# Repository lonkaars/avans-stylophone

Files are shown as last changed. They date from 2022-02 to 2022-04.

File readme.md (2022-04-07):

# avans-stylofoon

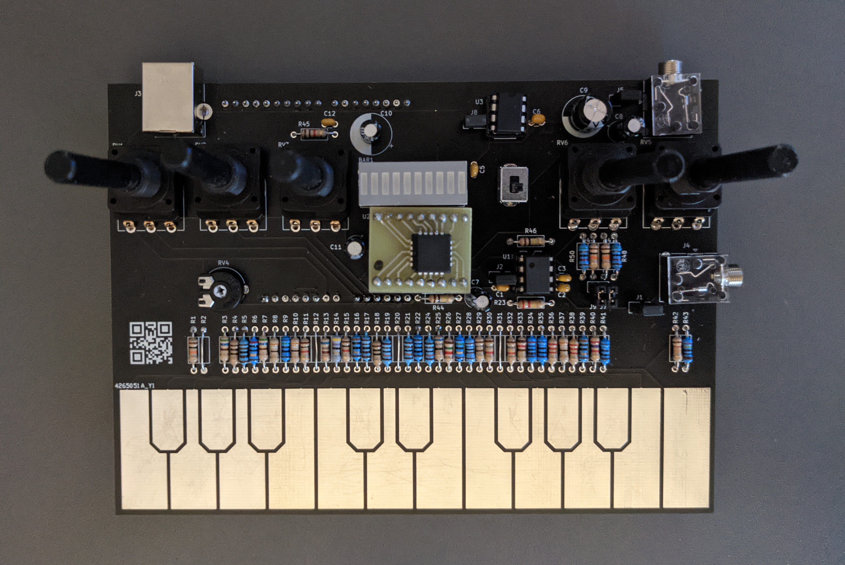
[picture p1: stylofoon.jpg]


(dutch)

bronnen voor project stylofoon van technische informatica bij hogeschool avans
in den bosch. hier staan alle kicad bestanden voor de elektrische schema's en
hardwareontwerpen, en alle documentatie die ingeleverd moet worden.

## advies voor andere studenten die dit project ook moeten doen

- Lees goed wat de 'gain' van de LM386 doet
- Maak je system requirements een beetje vaag (zie mijn system requirements),
	zo verlies je geen punten wanneer het uiteidendelijk blijkt dat je stylofoon
	ontzettend vals klinkt omdat de weerstanden niet helemaal kloppen
- Uitbereidingen zijn leuk, maar als ik het project opnieuw zou doen zou ik
	gewoon voor de 8 drukknoppen en shiftregister gaan, want uitbereidingen maken
	bij de stylofoon is lastig
- Onderzoek goed hoe je een constante 'drone'-toon kan vermijden (als je gaat
	voor de vco opstelling van de 555, de rco is hier waarschijnlijk niet
	gevoelig voor), anders maakt je stylofoon een contstante middentoon, inplaats
	van dat het stil is als je geen toets aanspeelt
- Er staan Sony speakers in het techlab, deze werken (in mijn geval slecht) en
	zorgde er (onder andere) voor dat mijn VU-display het niet goed deed.
- Speaker specificaties verschillen niet alleen in impedantie, maar ook enorm
	in gevoeligheid, dus het kan makkelijk aan de speaker liggen als je stylofoon
	geen 'fatsoenlijk volume' produceert.
- Maak veel system tests voor dingen die toch wel zullen werken, uiteidenlijk
	word je eindcijfer voor werking bepaald door het percentage van behaalde
	system tests, en onder de 90% geeft je al een 4. Dus als je bijvoorbeeld 18
	tests hebt kun je er maar 1 missen om nog een voldoende te halen.

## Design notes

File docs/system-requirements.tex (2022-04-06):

\documentclass[12pt, a4paper, dutch]{article}
\usepackage[margin=1in]{geometry}

\usepackage{float}
\usepackage{babel}
\usepackage{siunitx}
\usepackage{amsmath}
\usepackage{csquotes}
\usepackage{parskip}
\usepackage{unicode-math}
\usepackage{fontspec}
\usepackage{tabularx}
\usepackage{booktabs}
\usepackage{needspace}
\usepackage{graphicx}
\usepackage{hyperref}
% \usepackage[backend=biber,
% 	bibencoding=utf8,
% 	style=apa
% ]{biblatex}

\setmainfont{TeX Gyre Schola}
\setmathfont{TeX Gyre Schola Math}
\sisetup{
	group-separator = {.},
	output-decimal-marker = {,}
}

\bigskipamount=7mm
\medskipamount=4mm
\parindent=0mm

\newcommand{\req}[1]{$^{\text{\ref{req:#1}}}$}
\newcommand{\up}[1]{$^{\text{#1}}$}
\newcommand{\sub}[1]{$_{\text{#1}}$}

\begin{document}
System requirements \hfill \textbf{Loek Le Blansch (2180996)}\\
Project Stylofoon \hfill \today
\medskip

\section{Inleiding}

De stylofoon is een klein instrument die met behulp van een stylus bespeeld wordt. Op
de stylofoon zitten 20 contactpunten in de vorm van pianotoetsen. Het uiteinde van de
stylus bevat een elektrisch contact, die gebruikt wordt om de pianotoetsvormige
contacten aan te raken. De stylofoon heeft twee ingebouwde synthesizers, die mengbaar
zijn met behulp van een draaiknop om unieke geluiden te cre\"eren.

\begin{figure}[H]
	\centering
	
	\caption{Schets van de layout op de voor- en bovenkant}
\end{figure}

\section{Projectopdracht}

Hier is het originele verhaal van de opdrachtgever, met toegevoegde nummers om aan te
tonen hoe bepaalde eisen verwerkt zijn:

``Ik wil graag één muziekinstrument\req{20keys} die op twee verschillende manieren
geluid kan produceren\req{engines}, met een Stylofoon en Synthesizer. De Stylofoon
moet 20 tonen kunnen genereren\req{20keys}. De Synthesizer moet gebaseerd zijn op een
Arduino\req{engines} en 8 variabele tonen maken\req{readtone}\up{,}\req{wavform}. De
tonen die de Synthesizer maakt moeten met draaiknoppen instelbaar zijn op frequentie
en lengte\req{env}. Er moet een schakelaar aanwezig zijn om te wisselen tussen
het afspelen van de Stylofoon en Synthesizer\req{mixfader}. Het geluidsignaal moet
ook visueel gemaakt worden op een VU-meter\req{vumeter}. Het volume moet ingesteld
kunnen worden met een draaiknop\req{volknob}. De status van het gehele instrument
moet visueel weergegeven worden\req{powerbutton}. Het zou mooi zijn als in plaats van
een schakelaar er een manier is om de geluidssignalen van de Stylofoon en Synthesizer
te combineren\req{mixfader}.

De Stylofoon heeft minimaal 20 contactpunten\req{20keys} en is gebaseerd op een 555
timer\req{555}. De Synthesizer is gebaseerd op een Arduino Uno\req{engines} en heeft
minimaal 8 druktoetsen\req{readtone} en 2 draaiknoppen\req{digsoundtweak}. Verder is
er een draaiknop om het volume te regelen\req{volknob}, een
luidspreker-aansluiting\req{phonesout} en een VU-meter\req{vumeter}. Alleen pinnen
A0-A5 van de Arduino Uno mogen gebruikt worden\req{a05}.''

\section{Technische eisen}

In deze vereisten word er met het woord `synthesizer' alleen het elektrische
onderdeel dat een geluidssignaal produceert bedoeld, niet de stylofoon in zijn
geheel.

\begin{enumerate}
\subsection{Functionele specificaties}
	\item \label{req:20keys} \'E\'en fysiek klaviertoetsenbord bestaand uit 20
		elektrisch geleidende contacten
	\item \label{req:mixfader} Een draaiknop die het geluid van de analoge en de
		digitale synthesizers mixt voordat het signaal versterkt wordt
	\item \label{req:vumeter} Een 10-segments VU-meter die visueel de amplitude van het
		uigangssignaal laat zien
	\item \label{req:volknob} Een volumeknop om het uigangsvolume aan te passen
	\item \label{req:powerbutton} Een aan-uit knop op de voorkant die toont of de stylofoon
		aan staat
	\item \label{req:digsoundtweak} Draaiknoppen om eigenschappen van het geluid dat
		uit de digitale synthesizer komt aan te passen:
	\begin{enumerate}
		\item \label{req:toonsnelheid} \'E\'en draaiknop om de toonsnelheid te regelen
		\item \label{req:env} \'E\'en draaiknop om de `envelope' te regelen
		\item \label{req:wavform} \'E\'en draaiknop om de golfvorm te mengen of schakelen
			tussen een sinus-, driehoeks-, zaagtand- en blokgolf.
	\end{enumerate}
\subsection{Operationele functies}
	\item \label{req:engines} Twee synthesizers, een analoge en een digitale die met
		behulp van een Arduino Uno gemaakt wordt
	\begin{enumerate}
		\item \label{req:wavforms} De digitale synthesizer produceert vier verschillende
			golfvormen
		\item \label{req:readtone} De digitale synthesizer kan de huidige toon die
			gespeeld word uitlezen door de spanning over de weerstandsladder te meten
	\end{enumerate}
	\item \label{req:phonesout} De audio uitgang van de stylofoon wordt intern
		versterkt zijn om op headphone-level te komen
\subsection{Ontwerpbeperkingen}
	\item \label{req:555} De analoge synthesizer is gebaseerd op een 555 timer
	\item \label{req:a05} Alleen pinnen A0..A5 van de Arduino worden gebruikt
	\item \label{req:lm3914} Er wordt een LM3914 IC gebruikt voor de VU-meter
\subsection{Randvoorwaarden}
	\item Sommige componenten worden voorgeschreven
	\item Diverse componenten zoals de gaatjesprint, druktoetsen en leds worden door de
		labbeheerders geleverd
	\item Componenten die niet in voorraad zijn worden in overleg met de labbeheerders
		gekozen
	\item Er worden IC-voetjes gebruikt om de ledbar van de VU-meter, en andere IC's te
		monteren
\end{enumerate}

\end{document}

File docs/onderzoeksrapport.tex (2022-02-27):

\documentclass[12pt, a4paper, dutch]{article}
\usepackage[margin=1in]{geometry}

\usepackage{float}
\usepackage{babel}
\usepackage{siunitx}
\usepackage{amsmath}
\usepackage{csquotes}
\usepackage{parskip}
\usepackage{unicode-math}
\usepackage{fontspec}
\usepackage{tabularx}
\usepackage{booktabs}
\usepackage{needspace}
\usepackage{hyperref}
\usepackage{graphicx}
% \usepackage[backend=biber,
% 	bibencoding=utf8,
% 	style=apa
% ]{biblatex}

\setmainfont{TeX Gyre Schola}
\setmathfont{TeX Gyre Schola Math}
\sisetup{
	group-separator = {.},
	output-decimal-marker = {,}
}

\newcommand{\s}{$^{\sharp}$}
\newcommand{\sub}[1]{$_{\text{#1}}$}

\bigskipamount=7mm
\medskipamount=4mm
\parindent=0mm

\begin{document}
Onderzoeksrapport \hfill \textbf{Loek Le Blansch (2180996)}\\
Project Stylofoon \hfill \today
\medskip

\tableofcontents

\section{Veelgebruikte eenheden}

% \textit{Welke eenheden worden er gebruikt om stromen en spanningen in
% audio-circuits te meten?}

\textbf{V\sub{PP}} (voltage peak to peak)
Dit is de afstand tussen de onderste en bovenste spanningsgrens van een signaal

\textbf{V\sub{RMS}} (root mean square voltage)
Dit is de gelijkspanningequivalent van een wisselspanning. Voor een AC signaal
met een evenwichtsstand om \SI{0}{\volt} is V\sub{RMS} als volgt te berekenen:
\[ \text{V}_{\text{RMS}} = \frac{\text{V}_{\text{AC}}}{\sqrt{2}} \]

\textbf{dB} (decibel)
Decibel is de eenheid van relatief geluidsvolume. De schaalverdeling van decibel is
logaritmisch, om de manier waarop mensen volume waarnemen na te bootsen. Decibel is
een relatieve eenheid, en wordt daarom vaak gecombineerd met andere eenheden zoals
dBv (decibel voltage) of dB SPL (decibel sound pressure level) om absolute waardes
aan te geven.

\textbf{dBv} (decibel volt)
dBv is V\sub{RMS} relatief tot een spanning die \SI{1}{\milli\watt} zou verspillen
door een lading met een impedantie van \SI{600}{\ohm}. 0 dBv is gelijk aan een
spanning van $\sqrt{600 * 1 * 10^{-3}} \approx \SI{0.77}{\volt}$.

\textbf{W} (watt)
Omdat voor de amplitude van een signaal de spanning, en daarmee ook de stroom
verandert, is het gebruikelijk om op de uitgang van een versterker een vermogen te
zien. Er is alleen geen `normaal' vermogen, omdat de gevoeligheid van
uitvoerapparaten ook enorm kan vari\"eren. De IEM's die ik thuis gebruik zijn erg
gevoelig, en hebben een gevoeligheid van 112 dB SPL mW$^{-1}$.

\section{555 Timer configuratie}

% \textit{Hoe configureer je een 555 timer op een manier waarop de spanning of
% weerstand die de frequentie regelt meetbaar is zonder de frequentie te
% be\"invloeden, en de frequentie uitrekenbaar is?}

In het ontwerp gaat het keyboard van de noot f3 tot c5. Hier is een tabel met
nootnamen, absolute frequenties en de invoerspanning die de 555 oscillator nodig
heeft om die frequentie te produceren:

\begin{figure}[H]
\centering
\begin{tabular}{ccc}
\toprule
Noot & $f$ [\si{\hertz}] & V\sub{in} [\si{\volt}]\\
\midrule
f3   & \num{174.6} & \num{3.986} \\
f\s3 & \num{185.0} & \num{3.929} \\
g3   & \num{196.0} & \num{3.817} \\
g\s3 & \num{207.7} & \num{3.757} \\
a3   & \num{220.0} & \num{3.678} \\
a\s3 & \num{233.1} & \num{3.578} \\
b3   & \num{246.9} & \num{3.505} \\
c4   & \num{261.6} & \num{3.402} \\
c\s4 & \num{277.2} & \num{3.291} \\
d4   & \num{293.7} & \num{3.161} \\
d\s4 & \num{311.1} & \num{3.020} \\
e4   & \num{329.6} & \num{2.883} \\
f4   & \num{349.2} & \num{2.725} \\
f\s4 & \num{370.0} & \num{2.546} \\
g4   & \num{392.0} & \num{2.366} \\
g\s4 & \num{415.3} & \num{2.174} \\
a4   & \num{440.0} & \num{1.958} \\
a\s4 & \num{466.2} & \num{1.734} \\
b4   & \num{493.9} & \num{1.511} \\
c5   & \num{523.3} & \num{1.225} \\
\bottomrule
\end{tabular}
\caption{Noot-frequentie lookup-table}
\end{figure}

Deze metingen zijn gedaan met een voedingsspanning van \SI{5.00}{\volt}, een
weerstandwaarde van \SI{218.8}{\kilo\ohm}, en een condensator van
\SI{10.4}{\nano\farad}.

Uit deze tabel is te zien dat de frequentie tussen \SI{174.6}{\hertz} en
\SI{523.3}{\hertz} moet kunnen vari\"eren. Omdat er een weerstandsladder gebruikt
word voor het keyboard, moet er een manier zijn om te compenseren voor de toleranties
van de weerstanden. Hiervoor worden instelpotmeters in serie gesoldeerd die de
weerstandswaarde kunnen laten vari\"eren buiten de tolerantie van elke weerstand.

% Metingen frequentie bereken formule:
% 
% \begin{figure}[H]
% \centering
% \begin{tabular}{ccc}
% \toprule
% $f$ [\si{\hertz}] & R [\si{\kilo\ohm}]\\
% \midrule
% \num{373} & \num{218.8} \\
% \num{820} & \num{99.13} \\
% \num{1468} & \num{54.83} \\
% \bottomrule
% \end{tabular}
% \caption{Variabele weerstand bij condensator van \SI{10.4}{\nano\farad}}
% \end{figure}
% 
% \begin{figure}[H]
% \centering
% \begin{tabular}{ccc}
% \toprule
% $f$ [\si{\hertz}] & Q [\si{\nano\farad}]\\
% \midrule
% \num{184} & \num{21.0} \\
% \num{373} & \num{10.4} \\
% \num{676} & \num{5.54} \\
% \bottomrule
% \end{tabular}
% \caption{Variabele condensator bij weerstand van \SI{218.8}{\kilo\ohm}}
% \end{figure}

\section{Spanningen en stromen}

% \textit{Welke voedingen kunnen gebruikt worden om alle onderdelen te voorzien van
% genoeg stroom?}

Het hele systeem draait op een voedingsspanning van V\sub{CC} $=$ \SI{5.0}{\volt}.
Het zou ideaal zijn als de hele stylofoon door \'e\'en USB poort gevoed kan worden.
Een standaard USB aansluiting levert echter niet meer dan \SI{500}{\milli\ampere},
dus als alle onderdelen gecombineerd meer dan deze limiet gebruiken moet er een
andere oplossing voor de voeding gekozen worden.

% \subsection{Metingen}
% 
% \begin{figure}[H]
% \centering
% \begin{tabular}{lccl}
% \toprule
% Onderdeel \\
% \midrule
% Arduino (audio uit)                   & V\sub{RMS} & \num{0} & \si{\volt}\\
% 										                  & I\sub{RMS} & \num{0} & \si{\milli\ampere}\\
% 555 (audio uit)                       & V\sub{RMS} & \num{0} & \si{\volt}\\
%                                       & I\sub{RMS} & \num{0} & \si{\milli\ampere}\\
% Functiegenerator (fatsoenlijk volume) & V\sub{RMS} & \num{0} & \si{\volt}\\
% 																			& I\sub{RMS} & \num{0} & \si{\milli\ampere}\\
% \bottomrule
% \end{tabular}
% \caption{Gemeten stromen en spanningen}
% \end{figure}

\subsection{Uitvoer}

De uitvoer van de stylofoon moet volgens de opdrachtgever `een fatsoenlijk volume'
produceren. Op internet heb ik gevonden dat een gemiddelde koptelefoonaansluiting op
een smartphone ongeveer \SI{30}{\milli\watt} bij een koptelefoon met een impedantie
van \SI{32}{\ohm} levert. Het volume van een audiosignaal is lastig te achterhalen
omdat het van veel verschillende factoren af hangt zoals de spanning, vermogen,
impedantie, en de gevoeligheid van het uitvoerapparaat.

Genoeg vermogen leveren voor oordopjes zal niet heel lastig zijn, maar omdat de
gevoeligheid van speakers heel erg vari\"eert is het lastig om een exacte waarde te
geven. Daarom ga ik er vanaf nu vanuit dat \SI{30}{\milli\watt} @ \SI{32}{\ohm}
genoeg zal zijn. Hiermee kan de stroom die de stylofoon moet leveren uitgerekend
worden als volgt:

\[
I=\sqrt{\frac{P}{R}} = \sqrt{\frac{30*10^{-3}}{32}} \approx \SI{31}{\milli\ampere}
\]

\subsection{Overzicht}

\begin{figure}[H]
\centering
\begin{tabular}{lr}
\toprule
Onderdeel & I\sub{max} [\si{\milli\ampere}]\\
\midrule
Arduino & \num{50} \\
Arduino audio uit & \num{20} \\
555 & \num{3} \\
LM3914 & \num{13} \\
VU-display & \num{200} \\
LM386 & \num{4} \\
Audio-uitvoer & \num{31} \\
\midrule
\hfill Totaal: & \num{321} \\
\bottomrule
\end{tabular}
\caption{Overzicht stromen}
\end{figure}

\section{Versterkers}

% \textit{Hoe versterk je een audiosignaal zonder ruis of vervorming te
% introduceren?}

Om het audiosignaal hoorbaar te maken kunnen niet direct speakers aangesloten worden
op de interne synthesizers, maar deze moeten eerst versterkt worden. Audiosignalen
kunnen op verschillende manieren versterkt worden, maar voor dit project heb ik
gekozen om een LM386 te gebruiken als versterker. In de datasheet van deze IC staat
een voorbeeldopstelling:

\begin{figure}[H]
\centering
\includegraphics[
	clip,
	trim=70mm 130mm 70mm 100mm,
	page=8
]{../datasheets/lm386.pdf}
\caption{Voorbeeldopstelling LM386}
\end{figure}

In deze voorbeeldopstelling komt de audio binnen via de V\sub{IN} ingang. Deze ingang
staat in serie met een potmeter zodat het volume geregeld kan worden. De LM386 heeft
een standaardgain van 20, maar deze kan verhoogd worden door pin 1 en 8 met een
weerstand en condensator te verbinden. Hierdoor zal het geluid harder worden.

\end{document}

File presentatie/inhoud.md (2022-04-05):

# presentatie inhoud

## introductie doel / onderwerp

tijdens deze presentatie:
- algemene werking van de stylofoon uitleggen
- geïmplementeerde uitbereidingen
- tekortkomingen
- leermomenten
- demo

## functies / specificaties

- inplaats van shiftregister leest Arduino het toetsenbord uit
- werkt op een standaard usb 2.0 poort (2.5W max)
- mixer tussen de arduino en 555 synth
- extra knoppen om het arduino geluid aan te passen

## erkenning tekortkomingen / gepoogde oplossingen

- volumeknop stuk (waarom?)
- constante middentoon
- niet gestemd

## leermomenten

## korte samenvatting urenrapportage als uitsmijter ofzo

## demo

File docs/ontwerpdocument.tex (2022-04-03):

\documentclass[12pt, a4paper, dutch]{article}
\usepackage[margin=1in]{geometry}

\usepackage{float}
\usepackage{babel}
\usepackage{siunitx}
\usepackage{amsmath}
\usepackage{csquotes}
\usepackage{parskip}
\usepackage{unicode-math}
\usepackage{fontspec}
\usepackage{tabularx}
\usepackage{booktabs}
\usepackage{needspace}
\usepackage{hyperref}
\usepackage{graphicx}
% \usepackage[backend=biber,
% 	bibencoding=utf8,
% 	style=apa
% ]{biblatex}

\setmainfont{TeX Gyre Schola}
\setmathfont{TeX Gyre Schola Math}
\sisetup{
	group-separator = {.},
	output-decimal-marker = {,}
}

\bigskipamount=7mm
\medskipamount=4mm
\parindent=0mm

\begin{document}
Ontwerpdocument \hfill \textbf{Loek Le Blansch (2180996)}\\
Project Stylofoon \hfill \today
\medskip

In dit document staan alle ontwerpfasen van de stylofoon met eventuele verklaring van
ontwerpkeuzes. Aan het einde van dit document zitten kopieën van het elektrisch
schema en PCB ontwerp op ware grootte.

\section{Ontwerpschets}

\begin{figure}[H]
	\centering
	
	\caption{Schets van de knoppenlayout op de voor-, zij- en bovenkant}
\end{figure}

Voor de stylofoon wou ik graag dat alle in- en outputs naast het keyboard zelf op een
regel zouden liggen. Zo zou het makkelijk zijn om de status van het hele instrument
in \'e\'en oogopslag te zien. Ook is er een losse voedingsaansluiting aan de
bovenkant, en een tweede 3.5mm jack om de stylus los te kunnen koppelen.

\newpage
\section{Blokschema}

\begin{figure}[H]
	\centering
	
	\caption{Blokschema (niveau 1)}
\end{figure}

\begin{figure}[H]
	\centering
	
	\caption{Blokschema (niveau 2)}
\end{figure}

\newpage
\section{Elektrisch schema}

\begin{figure}[H]
	\centering
	\includegraphics[
		width=\textwidth,
		clip,
		trim=19.7mm 74mm 19mm 12mm,
	]{figs/eschema.pdf}
	\caption{Elektrisch schema}
\end{figure}

Voor de `555 vco' (555 voltage-controlled oscillator) is een minder gebruikelijke
opstelling van de 555 timer te zien. Ik heb voor deze opstelling gekozen omdat ik van
plan was de Arduino te gebruiken om uit te lezen welke toets er wordt gespeeld. Met
de aanbevolen opstelling uit de projectlessen werd een variabele weerstand gebruikt
om de toonhoogte die de 555 osillator produceert te veranderen, en dit zou het meten
met de Arduino lastig maken.

De weerstandswaardes voor de weerstandsladder zijn uitgerekend door eerst met een
oscilloscoop en de 555 opstelling op een breadboard de juiste spanningen voor de
benodigde frequenties te vinden. Vervolgens heb ik een spreadsheet programma gebruikt
om uit te rekenen waar deze spanningen vallen tussen 0 en 5V (vcc). Daarna heb ik een
totale weerstandswaarde van 50\si{\kilo\ohm} gekozen voor de weerstandsladder, en het
spreadsheet programma laten uitrekenen hoe groot de weerstanden tussen de toetsen
moeten zijn. Daarna heb ik een programma geschreven die de uitgerekende
weerstandswaardes van de spreadsheet opdeelt in weerstanden die in het techlab
beschikbaar zijn.

Voor de rest zijn de LM386 audio versterker opstelling en de LM3914 vu-meter
opstelling gelijk aan de aanbevolen toepassing uit hun datasheets, met als enige
uitzondering de toegevoegde peak detector van de vu-meter.

\section{PCB ontwerp}

\begin{figure}[H]
	\centering
	\includegraphics[
		width=\textwidth,
		clip,
		trim=19.7mm 81mm 122mm 15mm,
	]{figs/pcb.pdf}
	\caption{PCB ontwerp. Rood is voorkant, blauw is achterkant}
\end{figure}

Voor het PCB ontwerp heb ik geprobeerd kleine componenten (diode's, weerstanden en
keramische condensatoren) zo dicht mogelijk op de chips te plaatsen, zodat het
makkelijker zou zijn om lange lijnen te trekken over de rest van de printplaat zonder
te veel via's te gebruiken. Ook heb ik extra jumper headers toegevoegd zodat ik
metingen en nog eventuele correcties zou kunnen maken na de hand.

\end{document}

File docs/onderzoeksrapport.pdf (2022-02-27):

Onderzoeksrapport | Loek Le Blansch (2180996)
Project Stylofoon | 27 februari 2022

## Inhoudsopgave

1 Veelgebruikte eenheden | 1
2 555 Timer configuratie | 1
3 Spanningen en stromen | 2
4 Versterkers | 3

## 1 Veelgebruikte eenheden

VPP (voltage peak to peak) Dit is de afstand tussen de onderste en bovenste spanningsgrens van een signaal

VRMS (root mean square voltage) Dit is de gelijkspanningequivalent van een wisselspanning. Voor een AC signaal met een evenwichtsstand om 0 V is VRMS als volgt te berekenen:

VRMS =

VAC
√2

dB (decibel) Decibel is de eenheid van relatief geluidsvolume. De schaalverdeling van decibel is logaritmisch, om de manier waarop mensen volume waarnemen na te bootsen. Decibel is een relatieve eenheid, en wordt daarom vaak gecombineerd met andere eenheden zoals dBv (decibel voltage) of dB SPL (decibel sound pressure level) om absolute waardes aan te geven.

dBv (decibel volt) dBv is VRMS relatief tot een spanning die 1 mW zou verspillen door een lading met een impedantie van 600 Ω. 0 dBv is gelijk aan een spanning van √600 ∗ 1 ∗ 10⁻³ ≈ 0,77 V.

W (watt) Omdat voor de amplitude van een signaal de spanning, en daarmee ook de stroom verandert, is het gebruikelijk om op de uitgang van een versterker een vermogen te zien. Er is alleen geen ‘normaal’ vermogen, omdat de gevoeligheid van uitvoerapparaten ook enorm kan variëren. De IEM’s die ik thuis gebruik zijn erg gevoelig, en hebben een gevoeligheid van 112 dB SPL mW⁻¹.

## 2 555 Timer configuratie

In het ontwerp gaat het keyboard van de noot f3 tot c5. Hier is een tabel met nootnamen, absolute frequenties en de invoerspanning die de 555 oscillator nodig heeft om die frequentie te produceren:

Noot f [Hz] Vin [V]
f3 | 174,6 | 3,986
f
♯3 | 185,0 | 3,929
g3 | 196,0 | 3,817
g
♯3 | 207,7 | 3,757
a3 | 220,0 | 3,678
a
♯3 | 233,1 | 3,578
b3 | 246,9 | 3,505
c4 | 261,6 | 3,402
c
♯4 | 277,2 | 3,291
d4 | 293,7 | 3,161
d
♯4 | 311,1 | 3,020
e4 | 329,6 | 2,883
f4 | 349,2 | 2,725
f
♯4 | 370,0 | 2,546
g4 | 392,0 | 2,366
g
♯4 | 415,3 | 2,174
a4 | 440,0 | 1,958
a
♯4 | 466,2 | 1,734
b4 | 493,9 | 1,511
c5 | 523,3 | 1,225

Figuur 1: Noot-frequentie lookup-table

Deze metingen zijn gedaan met een voedingsspanning van 5,00 V, een weerstandwaarde van 218,8 kΩ, en een condensator van 10,4 nF.

Uit deze tabel is te zien dat de frequentie tussen 174,6 Hz en 523,3 Hz moet kunnen variëren. Omdat er een weerstandsladder gebruikt word voor het keyboard, moet er een manier zijn om te compenseren voor de toleranties van de weerstanden. Hiervoor worden instelpotmeters in serie gesoldeerd die de weerstandswaarde kunnen laten variëren buiten de tolerantie van elke weerstand.

## 3 Spanningen en stromen

Het hele systeem draait op een voedingsspanning van VCC = 5,0 V. Het zou ideaal zijn als de hele stylofoon door één USB poort gevoed kan worden. Een standaard USB aansluiting levert echter niet meer dan 500 mA, dus als alle onderdelen gecombineerd meer dan deze limiet gebruiken moet er een andere oplossing voor de voeding gekozen worden.

### 3.1 Uitvoer

De uitvoer van de stylofoon moet volgens de opdrachtgever ‘een fatsoenlijk volume’ produceren. Op internet heb ik gevonden dat een gemiddelde koptelefoonaansluiting op een smartphone ongeveer 30 mW bij een koptelefoon met een impedantie van 32 Ω levert. Het volume van een audiosignaal is lastig te achterhalen omdat het van veel verschillende factoren af hangt zoals de spanning, vermogen, impedantie, en de gevoeligheid van het uitvoerapparaat.

Genoeg vermogen leveren voor oordopjes zal niet heel lastig zijn, maar omdat de gevoeligheid van speakers heel erg variëert is het lastig om een exacte waarde te geven. Daarom ga ik er vanaf nu vanuit dat 30 mW @ 32 Ω genoeg zal zijn. Hiermee kan de stroom die de stylofoon moet leveren uitgerekend worden als volgt:

I = √
P
R

= √
30 ∗ 10⁻³
32 ≈ 31 mA

### 3.2 Overzicht

Onderdeel | Imax [mA]
Arduino | 50
Arduino audio uit | 20
555 | 3
LM3914 | 13
VU-display | 200
LM386 | 4
Audio-uitvoer | 31
Totaal: | 321

Figuur 2: Overzicht stromen

## 4 Versterkers

Om het audiosignaal hoorbaar te maken kunnen niet direct speakers aangesloten worden op de interne synthesizers, maar deze moeten eerst versterkt worden. Audiosignalen kunnen op verschillende manieren versterkt worden, maar voor dit project heb ik gekozen om een LM386 te gebruiken als versterker. In de datasheet van deze IC staat een voorbeeldopstelling:

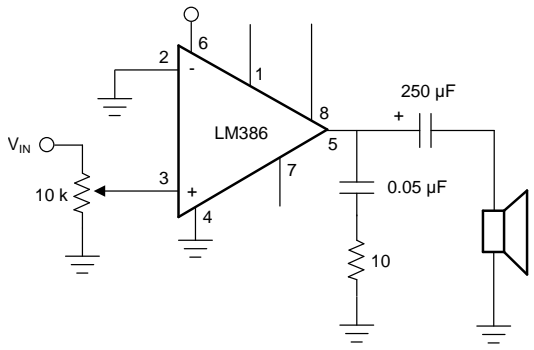
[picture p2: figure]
VIN

Figuur 3: Voorbeeldopstelling LM386

In deze voorbeeldopstelling komt de audio binnen via de VIN ingang. Deze ingang staat in serie met een potmeter zodat het volume geregeld kan worden. De LM386 heeft een standaardgain van 20, maar deze kan verhoogd worden door pin 1 en 8 met een weerstand en condensator te verbinden. Hierdoor zal het geluid harder worden.

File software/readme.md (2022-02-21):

een van de interne synthesizers die de stylofoon heeft is digitaal en gebaseerd
op een arduino uno. er moet gebruik gemaakt worden van de
[the\_synth](https://github.com/dzlonline/the_synth) bibliotheek, en deze wordt
in deze repository geimporteerd met behulp van git submodules. draai `git
submodule update --init --recursive --remote --merge` om de submodules te
downloaden/updaten als je van plan bent de code aan te passen of te compileren.

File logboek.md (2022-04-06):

# logboek

[link](https://docs.google.com/spreadsheets/d/1zp4gL5jmDVSvwYsKtnBXNt1g1LsAT9NwkqCPIc2atBc/edit?usp=sharing)
(ods ondersteunt geen tijdsverloop data format, alleen absolute tijd en ook
geen datum met tijd)

|datum|werktijd|onderdeel|
|-|-|-|
|Mon Feb  7 01:50:59 PM CET 2022|01:38:23|system requirements|
|Mon Feb  7 04:50:55 PM CET 2022|00:19:50|work breakdown structure|
|Sat Feb 12 11:28:00 AM CET 2022|03:32:40|case layout|
|Sat Feb 12 12:51:11 PM CET 2022|01:03:04|system requirements|
|Sat Feb 12 01:16:56 PM CET 2022|00:19:02|work breakdown structure|
|Sat Feb 12 03:21:54 PM CET 2022|01:22:00|system test|
|Sat Feb 12 07:28:36 PM CET 2022|00:45:00|blokschema|
|Tue Feb 15 12:24:14 PM CET 2022|01:07:09|elektrisch schema (tests)|
|Tue Feb 15 04:04:22 PM CET 2022|00:13:03|onderzoeksverslag (deelvragen)|
|Thu Feb 17 03:56:50 PM CET 2022|02:30:20|onderzoeksverslag (antwoorden)|
|Fri Feb 18 11:25:20 AM CET 2022|01:31:29|onderzoeksverslag (antwoorden)|
|Sat Feb 19 11:55:21 AM CET 2022|01:21:39|onderzoeksverslag (antwoorden)|
|Sat Feb 19 12:02:07 PM CET 2022|00:06:06|elektrisch schema (tests)|
|Sat Feb 19 12:19:30 PM CET 2022|00:16:03|blokschema|
|Mon Feb 21 03:33:44 PM CET 2022|00:12:42|elektrisch schema (organisatie)|
|Mon Feb 21 09:18:33 PM CET 2022|01:12:41|elektrisch schema (tests)|
|Mon Feb 21 09:38:40 PM CET 2022|00:19:12|software|
|Tue Feb 22 10:35:51 AM CET 2022|01:30:00|metingen / lab tests|
|Tue Feb 22 11:06:45 AM CET 2022|00:30:00|software testen / meten|
|Tue Feb 22 07:19:25 PM CET 2022|02:31:56|elektrisch schema|
|Wed Feb 23 11:13:05 AM CET 2022|00:45:00|metingen / lab tests|
|Wed Feb 23 01:38:37 PM CET 2022|00:30:00|elektrisch schema|
|Thu Feb 24 04:04:43 PM CET 2022|00:33:59|elektrisch schema|
|Fri Feb 25 03:35:05 PM CET 2022|01:00:44|elektrisch schema|
|Sat Feb 26 11:34:28 AM CET 2022|00:55:11|elektrisch schema|
|Sun Feb 27 04:37:40 PM CET 2022|00:57:17|onderzoeksverslag|
|Sun Feb 27 08:28:09 PM CET 2022|00:37:48|onderzoeksverslag|
|Tue Mar  8 05:13:47 PM CET 2022|03:30:58|elektrisch schema|
|Wed Mar  9 10:12:26 AM CET 2022|00:10:00|elektrisch schema|
|Wed Mar  9 02:09:42 PM CET 2022|01:34:22|elektrisch schema|
|Wed Mar  9 07:05:48 PM CET 2022|00:42:53|elektrisch schema|
|Thu Mar 10 05:24:24 PM CET 2022|00:28:16|elektrisch schema|
|Thu Mar 10 07:17:54 PM CET 2022|00:56:47|elektrisch schema|
|Fri Mar 11 12:13:38 PM CET 2022|02:30:00|lab tests|
|Fri Mar 11 02:27:19 PM CET 2022|00:40:00|elektrisch schema|
|Sat Mar 12 03:22:40 PM CET 2022|03:12:21|elektrisch schema|
|Sat Mar 12 06:37:00 PM CET 2022|00:30:00|qr code toevoegen aan pcb|
|Thu Mar 24 01:04:48 PM CET 2022|03:33:55|solderen / in mekaar zetten|
|Fri Mar 25 02:19:34 PM CET 2022|04:12:41|solderen / in mekaar zetten|
|Tue Mar 29 03:26:20 PM CET 2022|01:02:15|debuggen|
|Fri Apr  1 11:17:41 AM CEST 2022|02:03:32|debuggen en arduino software schrijven|
|Sat Apr  2 11:28:15 AM CEST 2022|00:34:51|software opschonen en ontwerpdocument maken|
|Sun Apr  3 06:56:56 PM CEST 2022|00:58:24|ontwerpdocument afmaken|
|Mon Apr  4 12:58:41 PM CEST 2022|00:37:00|begin presentatie schets maken|
|Tue Apr  5 06:27:48 PM CEST 2022|01:28:03|presentatie af|
|Wed Apr  6 11:36:36 AM CEST 2022|00:11:13|documenten doorkijken en corrigeren|

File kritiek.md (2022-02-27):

dit is een klaagmuur

- waarom moeten we de the_synth bibliotheek gebruiken? deze bibliotheek bevat:
	- geen documentatie naast wat voorbeelden
	- veel arbitraire getallen, die in commentaar uitgelegd worden in de
		voorbeelden, maar niet in de header die je importeert
	- code in header bestanden inplaats van een .h bestand voor de linker en een
		.ino bestand voor de compiler
	- geen mogelijkheid om gebruikt te worden in combinatie met de eis dat alleen
		pinnen a0 t/m a5 gebruikt worden, omdat de library alleen op pin d3 en d11
		werkt
- de audio uitgang moet 'fatsoenlijk volume' produceren, maar nergens worden
	specificaties gegeven van het uitvoerapparaat dat gebruikt wordt tijdens de
	assessment. dit is vervelend want speakers en koptelefoons hebben niet alleen
	wilde variatie in impedantie, maar ook gevoeligheid
- ik moet veels te veel vragen stellen aan de projectgever over kleine, maar
	belangrijke details; ik voel me een proefkonijn

als het project voorbij is ga ik misschien bij al deze problemen een oplossing
neerzetten en het terugkoppelen aan de docent ofzo

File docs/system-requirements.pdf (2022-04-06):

System requirements | Loek Le Blansch (2180996)
Project Stylofoon | 6 april 2022

## 1 Inleiding

De stylofoon is een klein instrument die met behulp van een stylus bespeeld wordt. Op de stylofoon zitten 20 contactpunten in de vorm van pianotoetsen. Het uiteinde van de stylus bevat een elektrisch contact, die gebruikt wordt om de pianotoetsvormige contacten aan te raken. De stylofoon heeft twee ingebouwde synthesizers, die mengbaar zijn met behulp van een draaiknop om unieke geluiden te creëren.

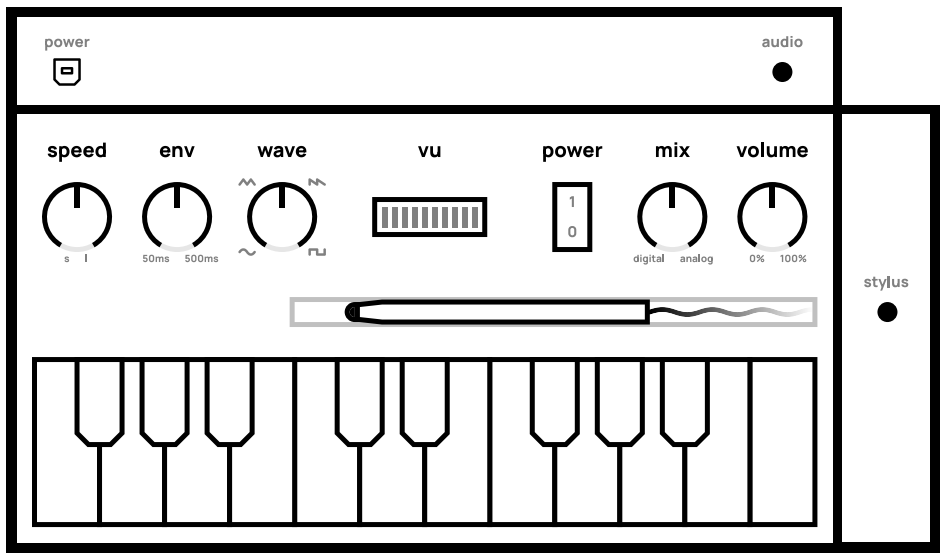
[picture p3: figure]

Figuur 1: Schets van de layout op de voor- en bovenkant

## 2 Projectopdracht

Hier is het originele verhaal van de opdrachtgever, met toegevoegde nummers om aan te tonen hoe bepaalde eisen verwerkt zijn:
“Ik wil graag één muziekinstrument¹ die op twee verschillende manieren geluid kan produceren⁷
, met een Stylofoon en Synthesizer. De Stylofoon moet 20 tonen kunnen genereren¹

. De Synthesizer moet gebaseerd zijn op een Arduino⁷ en 8 variabele tonen maken⁷b,6c. De tonen die de Synthesizer maakt moeten met draaiknoppen instelbaar zijn op frequentie en lengte⁶b. Er moet een schakelaar aanwezig zijn om te wisselen tussen het afspelen van de Stylofoon en Synthesizer²
. Het geluidsignaal moet ook visueel gemaakt worden op een VU-meter³
. Het volume moet
ingesteld kunnen worden met een draaiknop⁴
. De status van het gehele instrument moet visueel weergegeven worden⁵
. Het zou mooi zijn als in plaats van een schakelaar er een manier is om de geluidssignalen van de Stylofoon en Synthesizer te combineren²

De Stylofoon heeft minimaal 20 contactpunten¹ en is gebaseerd op een 555 timer⁹ .
De Synthesizer is gebaseerd op een Arduino Uno⁷ en heeft minimaal 8 druktoetsen⁷b en 2 draaiknoppen⁶

. Verder is er een draaiknop om het volume te regelen⁴ , een
luidspreker-aansluiting⁸ en een VU-meter³ . Alleen pinnen A0-A5 van de Arduino Uno mogen gebruikt worden¹⁰.”

## 3 Technische eisen

In deze vereisten word er met het woord ‘synthesizer’ alleen het elektrische onderdeel dat een geluidssignaal produceert bedoeld, niet de stylofoon in zijn geheel.

### 3.1 Functionele specificaties

1. Één fysiek klaviertoetsenbord bestaand uit 20 elektrisch geleidende contacten
2. Een draaiknop die het geluid van de analoge en de digitale synthesizers mixt voordat het signaal versterkt wordt
3. Een 10-segments VU-meter die visueel de amplitude van het uigangssignaal laat zien
4. Een volumeknop om het uigangsvolume aan te passen
5. Een aan-uit knop op de voorkant die toont of de stylofoon aan staat
6. Draaiknoppen om eigenschappen van het geluid dat uit de digitale synthesizer komt aan te passen:
(a) Één draaiknop om de toonsnelheid te regelen
(b) Één draaiknop om de ‘envelope’ te regelen
(c) Één draaiknop om de golfvorm te mengen of schakelen tussen een sinus-, driehoeks-, zaagtand- en blokgolf.

### 3.2 Operationele functies

7. Twee synthesizers, een analoge en een digitale die met behulp van een Arduino Uno gemaakt wordt
(a) De digitale synthesizer produceert vier verschillende golfvormen
(b) De digitale synthesizer kan de huidige toon die gespeeld word uitlezen door de spanning over de weerstandsladder te meten
8. De audio uitgang van de stylofoon wordt intern versterkt zijn om op headphonelevel te komen

### 3.3 Ontwerpbeperkingen

9. De analoge synthesizer is gebaseerd op een 555 timer

10. Alleen pinnen A0..A5 van de Arduino worden gebruikt
11. Er wordt een LM3914 IC gebruikt voor de VU-meter

### 3.4 Randvoorwaarden

12. Sommige componenten worden voorgeschreven
13. Diverse componenten zoals de gaatjesprint, druktoetsen en leds worden door de labbeheerders geleverd
14. Componenten die niet in voorraad zijn worden in overleg met de labbeheerders gekozen
15. Er worden IC-voetjes gebruikt om de ledbar van de VU-meter, en andere IC’s te monteren

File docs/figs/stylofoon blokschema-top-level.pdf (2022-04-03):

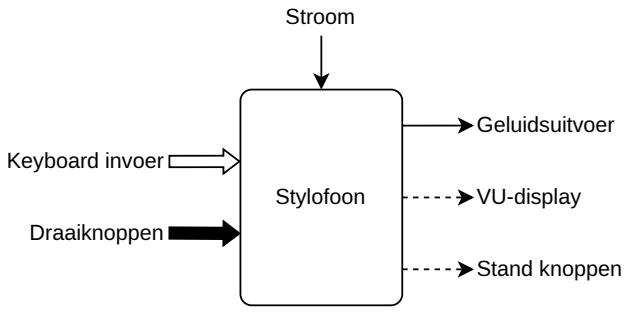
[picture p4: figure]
Stylofoon; Keyboard invoer; Draaiknoppen; Geluidsuitvoer; VU-display; Stand knoppen; Stroom

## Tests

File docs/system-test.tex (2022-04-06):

\documentclass[12pt, a4paper, dutch]{article}
\usepackage[margin=1in]{geometry}

\usepackage{float}
\usepackage{babel}
\usepackage{siunitx}
\usepackage{amsmath}
\usepackage{csquotes}
\usepackage{parskip}
\usepackage{unicode-math}
\usepackage{fontspec}
\usepackage{tabularx}
\usepackage{booktabs}
\usepackage{needspace}
\usepackage{graphicx}
\usepackage{hyperref}
\usepackage{bbding}
% \usepackage[backend=biber,
% 	bibencoding=utf8,
% 	style=apa
% ]{biblatex}

\setmainfont{TeX Gyre Schola}
\setmathfont{TeX Gyre Schola Math}
\sisetup{
	group-separator = {.},
	output-decimal-marker = {,}
}

\bigskipamount=7mm
\medskipamount=4mm
\parindent=0mm
\renewcommand{\arraystretch}{1.4}

\newcommand{\req}[1]{$^{\text{\ref{req:#1}}}$}
\newcommand{\up}[1]{$^{\text{#1}}$}
\newcommand{\sub}[1]{$_{\text{#1}}$}
\newcommand{\cb}{\Square}

\newcommand{\stroom}{De stylofoon is aangesloten op een voeding}
\newcommand{\audio}{De audiouitgang is aangesloten op een speaker of koptelefoon}
\newcommand{\aan}{De aan/uit knop staat op AAN}
\newcommand{\vol}{De volumeknop staat ingesteld op een hoorbaar niveau}

\begin{document}
System test \hfill \textbf{Loek Le Blansch (2180996)}\\
Project Stylofoon \hfill \today
\medskip

\tableofcontents

\newpage
\section{Tests}

\subsection{Draaiknop analoge/digitale synthesizer mixer}

\begin{minipage}{\textwidth}
\textbf{Beginsituatie}
\begin{itemize}
	\item \stroom
	\item \audio
	\item \aan
	\item \vol
\end{itemize}

\medskip

\begin{tabularx}{\textwidth}{p{0.5\textwidth}p{0.3\textwidth}>{\raggedleft\arraybackslash}X}
\toprule
\textbf{Actie} & \textbf{Resultaat} & \textbf{Check}\\
\midrule
Houd de stylus op een van de toetsen &
Er klinkt geluid &
\cb\\

Draai de knop die als `mix' gelabeld staat terwijl de stylus nog een van de
toetsen aan raakt &
De klank van het geluid veranderd, maar er valt geen stilte &
\cb\\
\bottomrule
\end{tabularx}
\end{minipage}

\subsection{VU-display}

\begin{minipage}{\textwidth}
\textbf{Beginsituatie}
\begin{itemize}
	\item \stroom
	\item \aan
\end{itemize}

\medskip

\begin{tabularx}{\textwidth}{p{0.5\textwidth}p{0.3\textwidth}>{\raggedleft\arraybackslash}X}
\toprule
\textbf{Actie} & \textbf{Resultaat} & \textbf{Check}\\
\midrule
Houd de stylus op een van de toetsen &
De VU-meter licht op &
\cb\\

Draai de knop die als `volume' gelabeld staat terwijl de stylus nog een van de
toetsen aan raakt &
Het aantal segmenten die opgelicht zijn verandert afhankelijk van hoe luid het
instrument klinkt &
\cb\\
\bottomrule
\end{tabularx}
\end{minipage}

\subsection{Volumeknop}

\begin{minipage}{\textwidth}
\textbf{Beginsituatie}
\begin{itemize}
	\item \stroom
	\item \audio
	\item \aan
	\item \vol
\end{itemize}

\medskip

\begin{tabularx}{\textwidth}{p{0.5\textwidth}p{0.3\textwidth}>{\raggedleft\arraybackslash}X}
\toprule
\textbf{Actie} & \textbf{Resultaat} & \textbf{Check}\\
\midrule
Houd de stylus op een van de toetsen &
Er klinkt geluid &
\cb\\

Draai de volumeknop tegen de klok in &
Het geluid word zachter &
\cb\\

Draai de volumeknop met de klok mee &
Het geluid word harder &
\cb\\
\bottomrule
\end{tabularx}
\end{minipage}

\subsection{Aan/uit knop}

\begin{minipage}{\textwidth}
\textbf{Beginsituatie}
\begin{itemize}
	\item \stroom
	\item \audio
	\item \vol
	\item De aan/uit knop staat op UIT
\end{itemize}

\medskip

\begin{tabularx}{\textwidth}{p{0.5\textwidth}p{0.3\textwidth}>{\raggedleft\arraybackslash}X}
\toprule
\textbf{Actie} & \textbf{Resultaat} & \textbf{Check}\\
\midrule
Houd de stylus op een van de toetsen &
Er klinkt geen geluid &
\cb\\

Zet de aan/uit knop op AAN &
Er gebeurt niks &
\cb\\

Houd de stylus op een van de toetsen &
Er klinkt geluid &
\cb\\
\bottomrule
\end{tabularx}
\end{minipage}

\subsection{Draaiknoppen van de digitale synthesizer}

\subsubsection{Draaiknop speed}

\begin{minipage}{\textwidth}
\textbf{Beginsituatie}
\begin{itemize}
	\item \stroom
	\item \audio
	\item \aan
	\item \vol
	\item De `mix' draaiknop staat volledig naar rechts gedraaid
	\item De `speed' draaiknop staat volledig naar links gedraaid
\end{itemize}

\medskip

\begin{tabularx}{\textwidth}{p{0.5\textwidth}p{0.3\textwidth}>{\raggedleft\arraybackslash}X}
\toprule
\textbf{Actie} & \textbf{Resultaat} & \textbf{Check}\\
\midrule
Tik met de stylus een toets aan &
Het klinkt alsof er een toon herhaaldelijk wordt aangetoetst met een matige snelheid &
\cb\\

Draai de `speed' knop volledig naar rechts &
Er gebeurt niks &
\cb\\

Tik met de stylus een toets aan &
De herhaaldelijke toetsaanslagen klinken sneller &
\cb\\
\bottomrule
\end{tabularx}
\end{minipage}

\subsubsection{Draaiknop envelope}

\begin{minipage}{\textwidth}
\textbf{Beginsituatie}
\begin{itemize}
	\item \stroom
	\item \audio
	\item \aan
	\item \vol
	\item De `mix' draaiknop staat volledig naar rechts gedraaid
	\item De `speed' draaiknop staat volledig naar links gedraaid
	\item De `envelope' draaiknop staat volledig naar links gedraaid
\end{itemize}

\medskip

\begin{tabularx}{\textwidth}{p{0.5\textwidth}p{0.3\textwidth}>{\raggedleft\arraybackslash}X}
\toprule
\textbf{Actie} & \textbf{Resultaat} & \textbf{Check}\\
\midrule
Tik met de stylus een toets aan &
Het herhaaldelijke geluid stopt snel &
\cb\\

Draai de `release' knop volledig naar rechts &
Er gebeurt niks &
\cb\\

Tik met de stylus een toets aan &
Het herhaaldelijke geluid loopt geleidelijk af &
\cb\\
\bottomrule
\end{tabularx}
\end{minipage}

\subsubsection{Draaiknop golfvorm}

\begin{minipage}{\textwidth}
\textbf{Beginsituatie}
\begin{itemize}
	\item \stroom
	\item \audio
	\item \aan
	\item \vol
	\item De `mix' draaiknop staat volledig naar rechts gedraaid
	\item De `wave' draaiknop staat volledig naar links gedraaid
\end{itemize}

\medskip

\begin{tabularx}{\textwidth}{p{0.5\textwidth}p{0.3\textwidth}>{\raggedleft\arraybackslash}X}
\toprule
\textbf{Actie} & \textbf{Resultaat} & \textbf{Check}\\
\midrule
Blijf de stylus op een van de toetsen houden &
Er klinkt een toon met een sinus-golfvorm &
\cb\\

Draai de `wave' knop een kwartslag naar rechts zodat deze nu op de driehoeksgolf
staat &
Het geluid verandert van een sinus naar een driehoeksgolf &
\cb\\

Draai de `wave' knop een kwartslag naar rechts zodat deze nu op de zaagtandgolf
staat &
Het geluid verandert van een driehoeksgolf naar een zaagtandgolf &
\cb\\

Draai de `wave' knop een kwartslag naar rechts zodat deze nu op de blokgolf staat &
Het geluid verandert van een zaagtandgolf naar een blokgolf &
\cb\\
\bottomrule
\end{tabularx}
\end{minipage}

\subsection{Interne versterker}

\begin{minipage}{\textwidth}
\textbf{Beginsituatie}
\begin{itemize}
	\item \stroom
	\item \audio
	\item \aan
	\item De volumeknop staat volledig naar links gedraaid
\end{itemize}

\medskip

\begin{tabularx}{\textwidth}{p{0.5\textwidth}p{0.3\textwidth}>{\raggedleft\arraybackslash}X}
\toprule
\textbf{Actie} & \textbf{Resultaat} & \textbf{Check}\\
\midrule
Blijf de stylus op een van de toetsen houden &
Er is geen geluid &
\cb\\

Draai de volumeknop langzaam volledig naar rechts &
Het geluid wordt langzaam luider, en het uitgangssignaal is sterk genoeg om
fatsoenlijk volume te cre\"eren uit het uitvoerapparaat &
\cb\\
\bottomrule
\end{tabularx}
\end{minipage}

\end{document}

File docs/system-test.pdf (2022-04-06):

System test | Loek Le Blansch (2180996)
Project Stylofoon | 6 april 2022

## Inhoudsopgave

1 Tests | 2

## 1 Tests

### 1.1 Draaiknop analoge/digitale synthesizer mixer

Beginsituatie
- De stylofoon is aangesloten op een voeding
- De audiouitgang is aangesloten op een speaker of koptelefoon
- De aan/uit knop staat op AAN
- De volumeknop staat ingesteld op een hoorbaar niveau
Actie | Resultaat | Check
Houd de stylus op een van de toetsen | Er klinkt geluid | f
Draai de knop die als ‘mix’ gelabeld staat terwijl de stylus nog een van de toetsen aan raakt | De klank van het geluid veranderd, maar er valt geen stilte | f

### 1.2 VU-display

Beginsituatie
- De stylofoon is aangesloten op een voeding
- De aan/uit knop staat op AAN
Actie | Resultaat | Check
Houd de stylus op een van de toetsen | De VU-meter licht op | f
Draai de knop die als ‘volume’ gelabeld staat terwijl de stylus nog een van de toet- sen aan raakt | Het aantal segmenten die opgelicht zijn ver- andert afhankelijk van hoe luid het instrument klinkt | f

### 1.3 Volumeknop

Beginsituatie
- De stylofoon is aangesloten op een voeding
- De audiouitgang is aangesloten op een speaker of koptelefoon
- De aan/uit knop staat op AAN
- De volumeknop staat ingesteld op een hoorbaar niveau
Actie | Resultaat | Check
Houd de stylus op een van de toetsen | Er klinkt geluid | f
Draai de volumeknop tegen de klok in | Het geluid word zachter | f
Draai de volumeknop met de klok mee | Het geluid word harder | f

### 1.4 Aan/uit knop

Beginsituatie
- De stylofoon is aangesloten op een voeding
- De audiouitgang is aangesloten op een speaker of koptelefoon
- De volumeknop staat ingesteld op een hoorbaar niveau
- De aan/uit knop staat op UIT
Actie | Resultaat | Check
Houd de stylus op een van de toetsen | Er klinkt geen geluid | f
Zet de aan/uit knop op AAN | Er gebeurt niks | f
Houd de stylus op een van de toetsen | Er klinkt geluid | f

### 1.5 Draaiknoppen van de digitale synthesizer

### 1.5.1 Draaiknop speed

Beginsituatie
- De stylofoon is aangesloten op een voeding
- De audiouitgang is aangesloten op een speaker of koptelefoon
- De aan/uit knop staat op AAN
- De volumeknop staat ingesteld op een hoorbaar niveau
- De ‘mix’ draaiknop staat volledig naar rechts gedraaid
- De ‘speed’ draaiknop staat volledig naar links gedraaid
Actie | Resultaat | Check
Tik met de stylus een toets aan | Het klinkt alsof er een toon herhaaldelijk wordt aangetoetst met een ma- tige snelheid | f
Draai de ‘speed’ knop volledig naar rechts Er gebeurt niks | f
Tik met de stylus een toets aan | De herhaaldelijke toets-
aanslagen klinken sneller

f

### 1.5.2 Draaiknop envelope

Beginsituatie
- De stylofoon is aangesloten op een voeding
- De audiouitgang is aangesloten op een speaker of koptelefoon
- De aan/uit knop staat op AAN
- De volumeknop staat ingesteld op een hoorbaar niveau
- De ‘mix’ draaiknop staat volledig naar rechts gedraaid
- De ‘speed’ draaiknop staat volledig naar links gedraaid
- De ‘envelope’ draaiknop staat volledig naar links gedraaid
Actie | Resultaat | Check
Tik met de stylus een toets aan | Het herhaaldelijke ge- luid stopt snel | f
Draai de ‘release’ knop volledig naar rechts | Er gebeurt niks | f
Tik met de stylus een toets aan | Het herhaaldelijke ge- luid loopt geleidelijk af | f

### 1.5.3 Draaiknop golfvorm

Beginsituatie
- De stylofoon is aangesloten op een voeding
- De audiouitgang is aangesloten op een speaker of koptelefoon
- De aan/uit knop staat op AAN
- De volumeknop staat ingesteld op een hoorbaar niveau
- De ‘mix’ draaiknop staat volledig naar rechts gedraaid
- De ‘wave’ draaiknop staat volledig naar links gedraaid
Actie | Resultaat | Check
Blijf de stylus op een van de toetsen hou- den | Er klinkt een toon met een sinus-golfvorm | f
Draai de ‘wave’ knop een kwartslag naar rechts zodat deze nu op de driehoeksgolf staat | Het geluid verandert van een sinus naar een driehoeksgolf | f

Draai de ‘wave’ knop een kwartslag naar
rechts zodat deze nu op de zaagtandgolf staat

Het geluid verandert
van een driehoeksgolf
naar een zaagtandgolf

f

Draai de ‘wave’ knop een kwartslag naar rechts zodat deze nu op de blokgolf staat

Het geluid verandert
van een zaagtandgolf
naar een blokgolf

f

### 1.6 Interne versterker

Beginsituatie
- De stylofoon is aangesloten op een voeding
- De audiouitgang is aangesloten op een speaker of koptelefoon
- De aan/uit knop staat op AAN
- De volumeknop staat volledig naar links gedraaid
Actie | Resultaat | Check
Blijf de stylus op een van de toetsen hou- den | Er is geen geluid | f
Draai de volumeknop langzaam volledig naar rechts | Het geluid wordt lang- zaam luider, en het uit- gangssignaal is sterk ge- noeg om fatsoenlijk vo- lume te creëren uit het uitvoerapparaat | f

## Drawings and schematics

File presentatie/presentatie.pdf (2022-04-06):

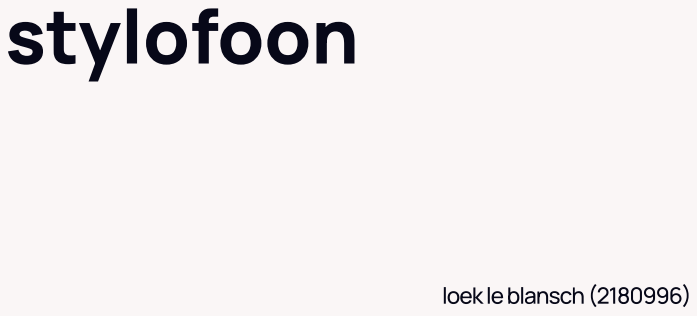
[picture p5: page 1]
stylofoon

loek le blansch (2180996)

# in deze presentatie

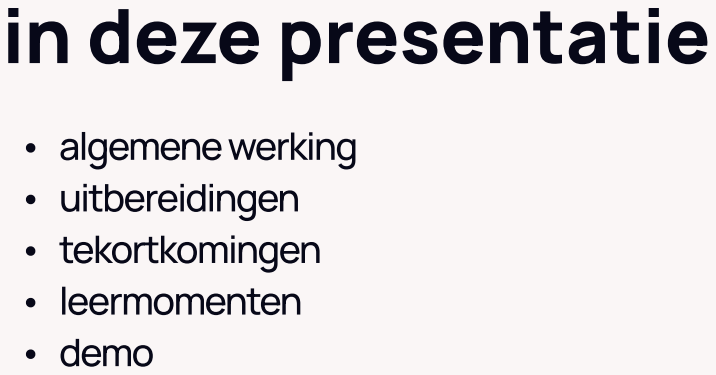
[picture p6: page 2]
 algemene werkin  uitbereidinge  tekortkominge  leermomente  demo

# algemene werking

# uitbereidingen

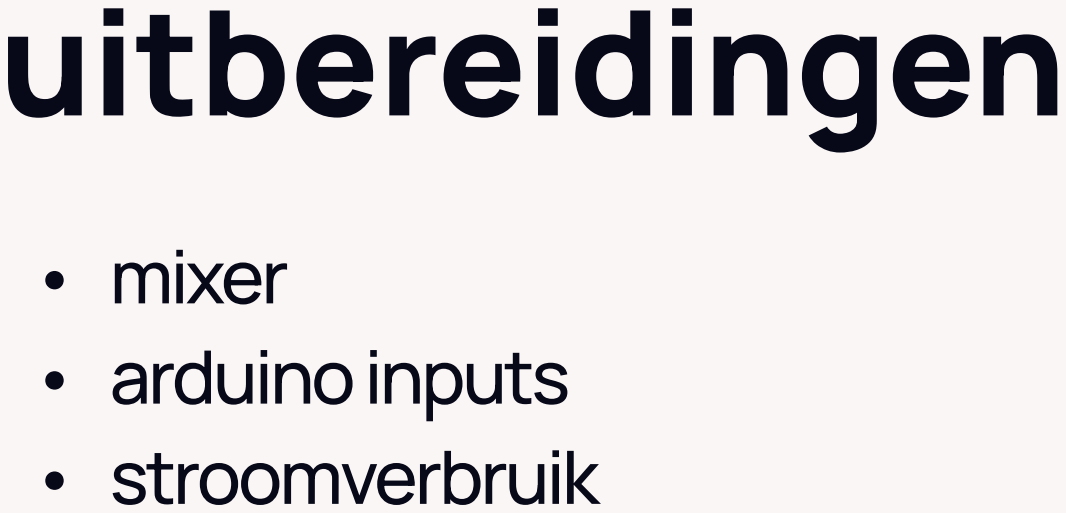
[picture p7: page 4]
 mixe  arduino input  stroomverbruik

# tekortkomingen

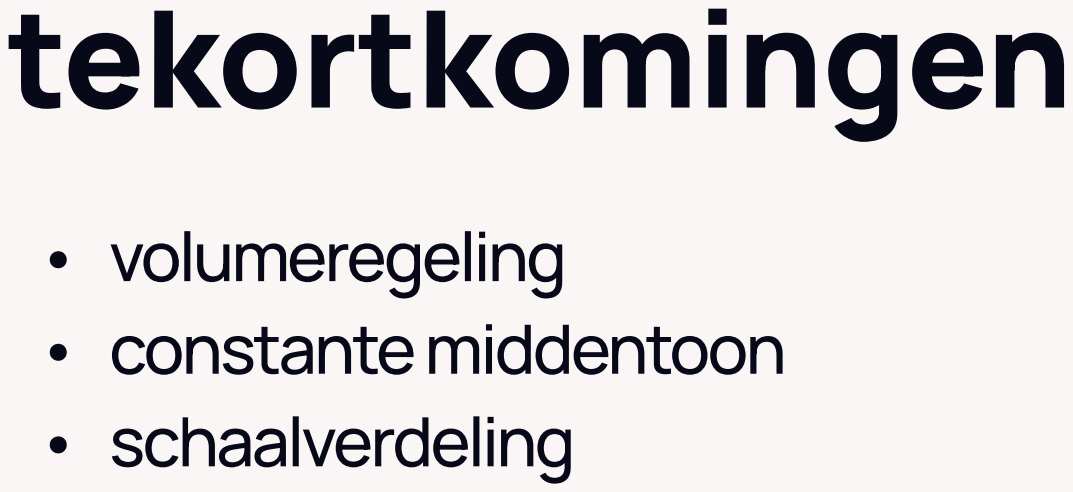
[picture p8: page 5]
 volumeregelin  constante middentoo  schaalverdeling

# leermomenten

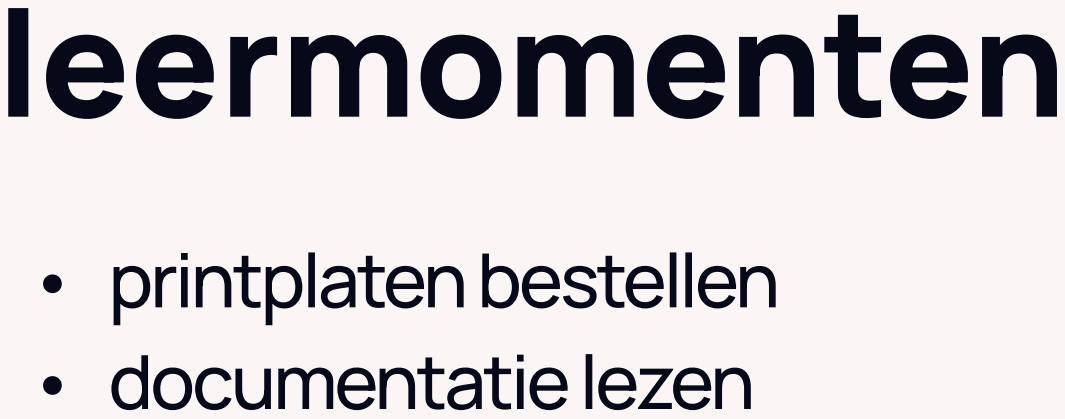
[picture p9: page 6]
 printplaten bestelle  documentatie lezen

### demo

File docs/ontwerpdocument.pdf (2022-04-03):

Ontwerpdocument | Loek Le Blansch (2180996)
Project Stylofoon | 3 april 2022

In dit document staan alle ontwerpfasen van de stylofoon met eventuele verklaring van ontwerpkeuzes. Aan het einde van dit document zitten kopieën van het elektrisch schema en PCB ontwerp op ware grootte.

## 1 Ontwerpschets

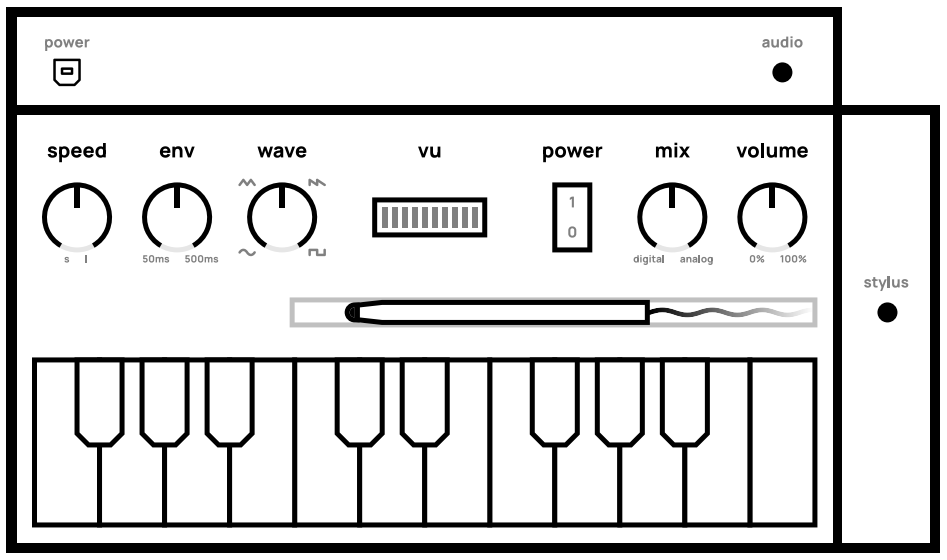
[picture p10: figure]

Figuur 1: Schets van de knoppenlayout op de voor-, zij- en bovenkant

Voor de stylofoon wou ik graag dat alle in- en outputs naast het keyboard zelf op een regel zouden liggen. Zo zou het makkelijk zijn om de status van het hele instrument in één oogopslag te zien. Ook is er een losse voedingsaansluiting aan de bovenkant, en een tweede 3.5mm jack om de stylus los te kunnen koppelen.

## 2 Blokschema

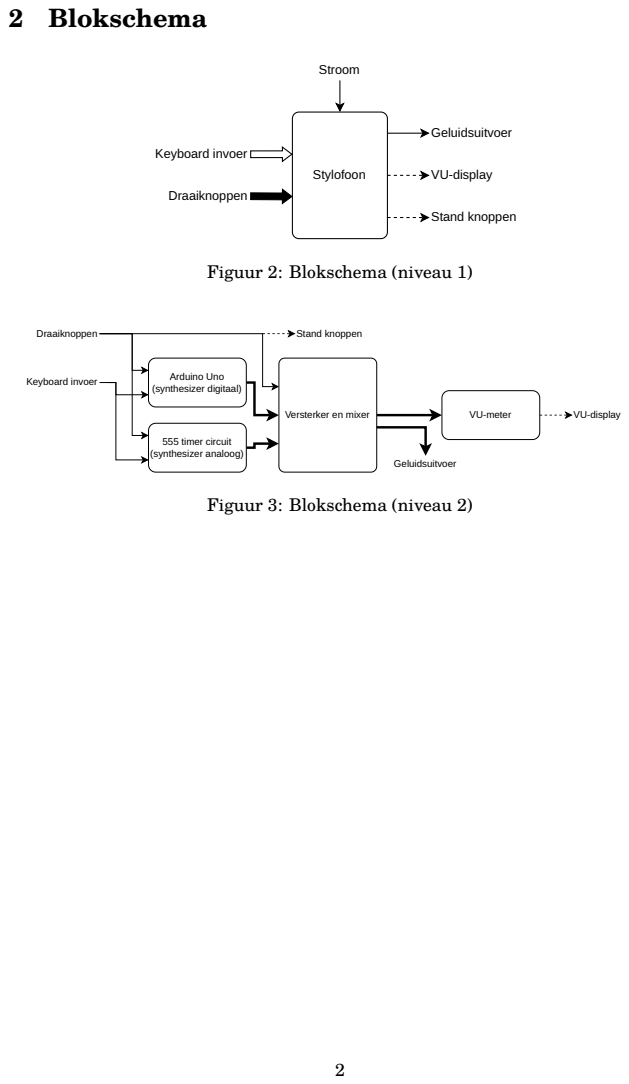
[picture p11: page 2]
Stylofoon; Keyboard invoer; Draaiknoppen; Geluidsuitvoer; VU-display; Stand knoppen; Stroom; Arduino Uno (synthesizer digitaal); 555 timer circuit (synthesizer analoog); Versterker en mixer; VU-meter

Figuur 2: Blokschema (niveau 1)

Figuur 3: Blokschema (niveau 2)

## 3 Elektrisch schema

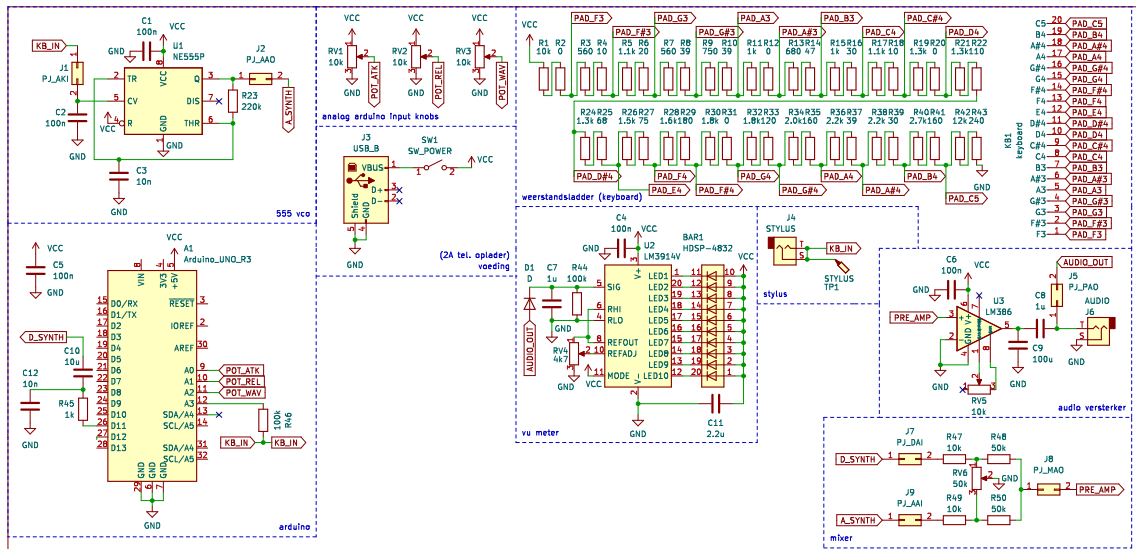
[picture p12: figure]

Figuur 4: Elektrisch schema

Voor de ‘555 vco’ (555 voltage-controlled oscillator) is een minder gebruikelijke opstelling van de 555 timer te zien. Ik heb voor deze opstelling gekozen omdat ik van plan was de Arduino te gebruiken om uit te lezen welke toets er wordt gespeeld. Met de aanbevolen opstelling uit de projectlessen werd een variabele weerstand gebruikt om de toonhoogte die de 555 osillator produceert te veranderen, en dit zou het meten met de Arduino lastig maken.

De weerstandswaardes voor de weerstandsladder zijn uitgerekend door eerst met een oscilloscoop en de 555 opstelling op een breadboard de juiste spanningen voor de benodigde frequenties te vinden. Vervolgens heb ik een spreadsheet programma gebruikt om uit te rekenen waar deze spanningen vallen tussen 0 en 5V (vcc). Daarna heb ik een totale weerstandswaarde van 50kΩ gekozen voor de weerstandsladder, en het spreadsheet programma laten uitrekenen hoe groot de weerstanden tussen de toetsen moeten zijn. Daarna heb ik een programma geschreven die de uitgerekende weerstandswaardes van de spreadsheet opdeelt in weerstanden die in het techlab beschikbaar zijn.

Voor de rest zijn de LM386 audio versterker opstelling en de LM3914 vu-meter opstelling gelijk aan de aanbevolen toepassing uit hun datasheets, met als enige uitzondering de toegevoegde peak detector van de vu-meter.

## 4 PCB ontwerp

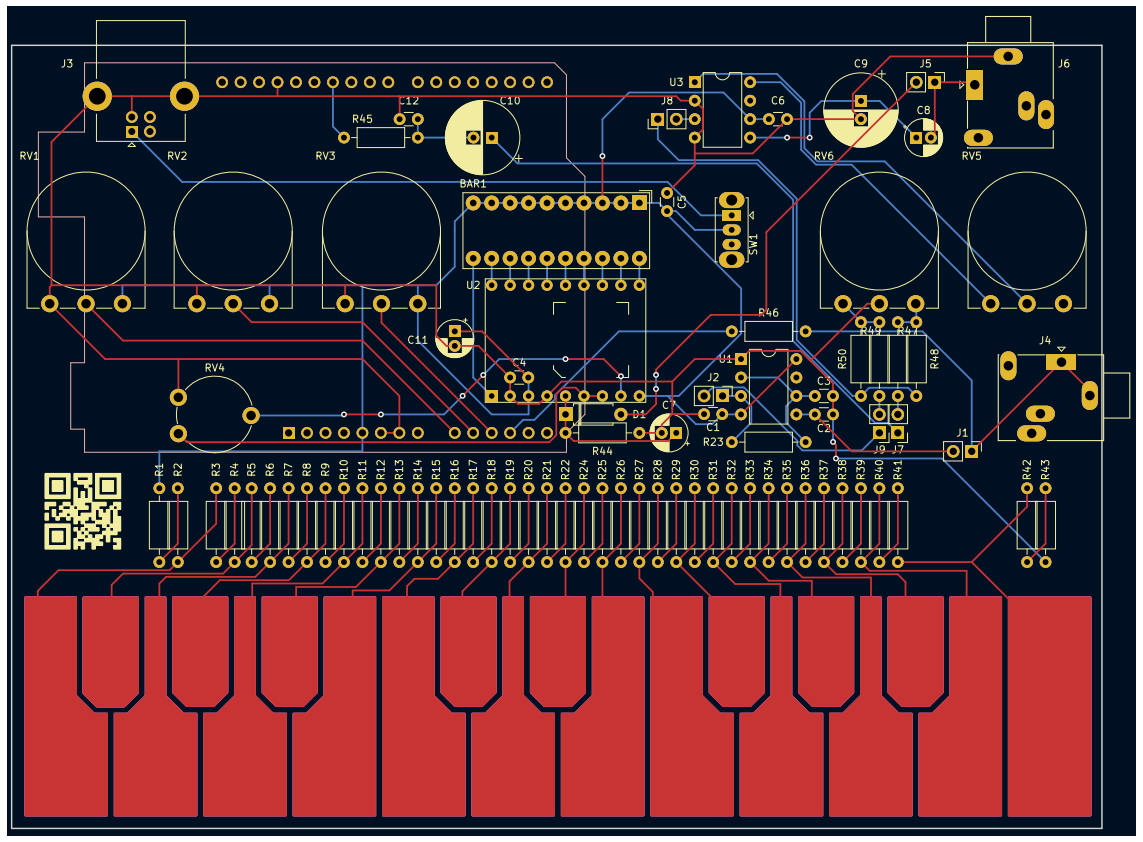
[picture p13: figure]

Figuur 5: PCB ontwerp. Rood is voorkant, blauw is achterkant

Voor het PCB ontwerp heb ik geprobeerd kleine componenten (diode’s, weerstanden en keramische condensatoren) zo dicht mogelijk op de chips te plaatsen, zodat het makkelijker zou zijn om lange lijnen te trekken over de rest van de printplaat zonder te veel via’s te gebruiken. Ook heb ik extra jumper headers toegevoegd zodat ik metingen en nog eventuele correcties zou kunnen maken na de hand.

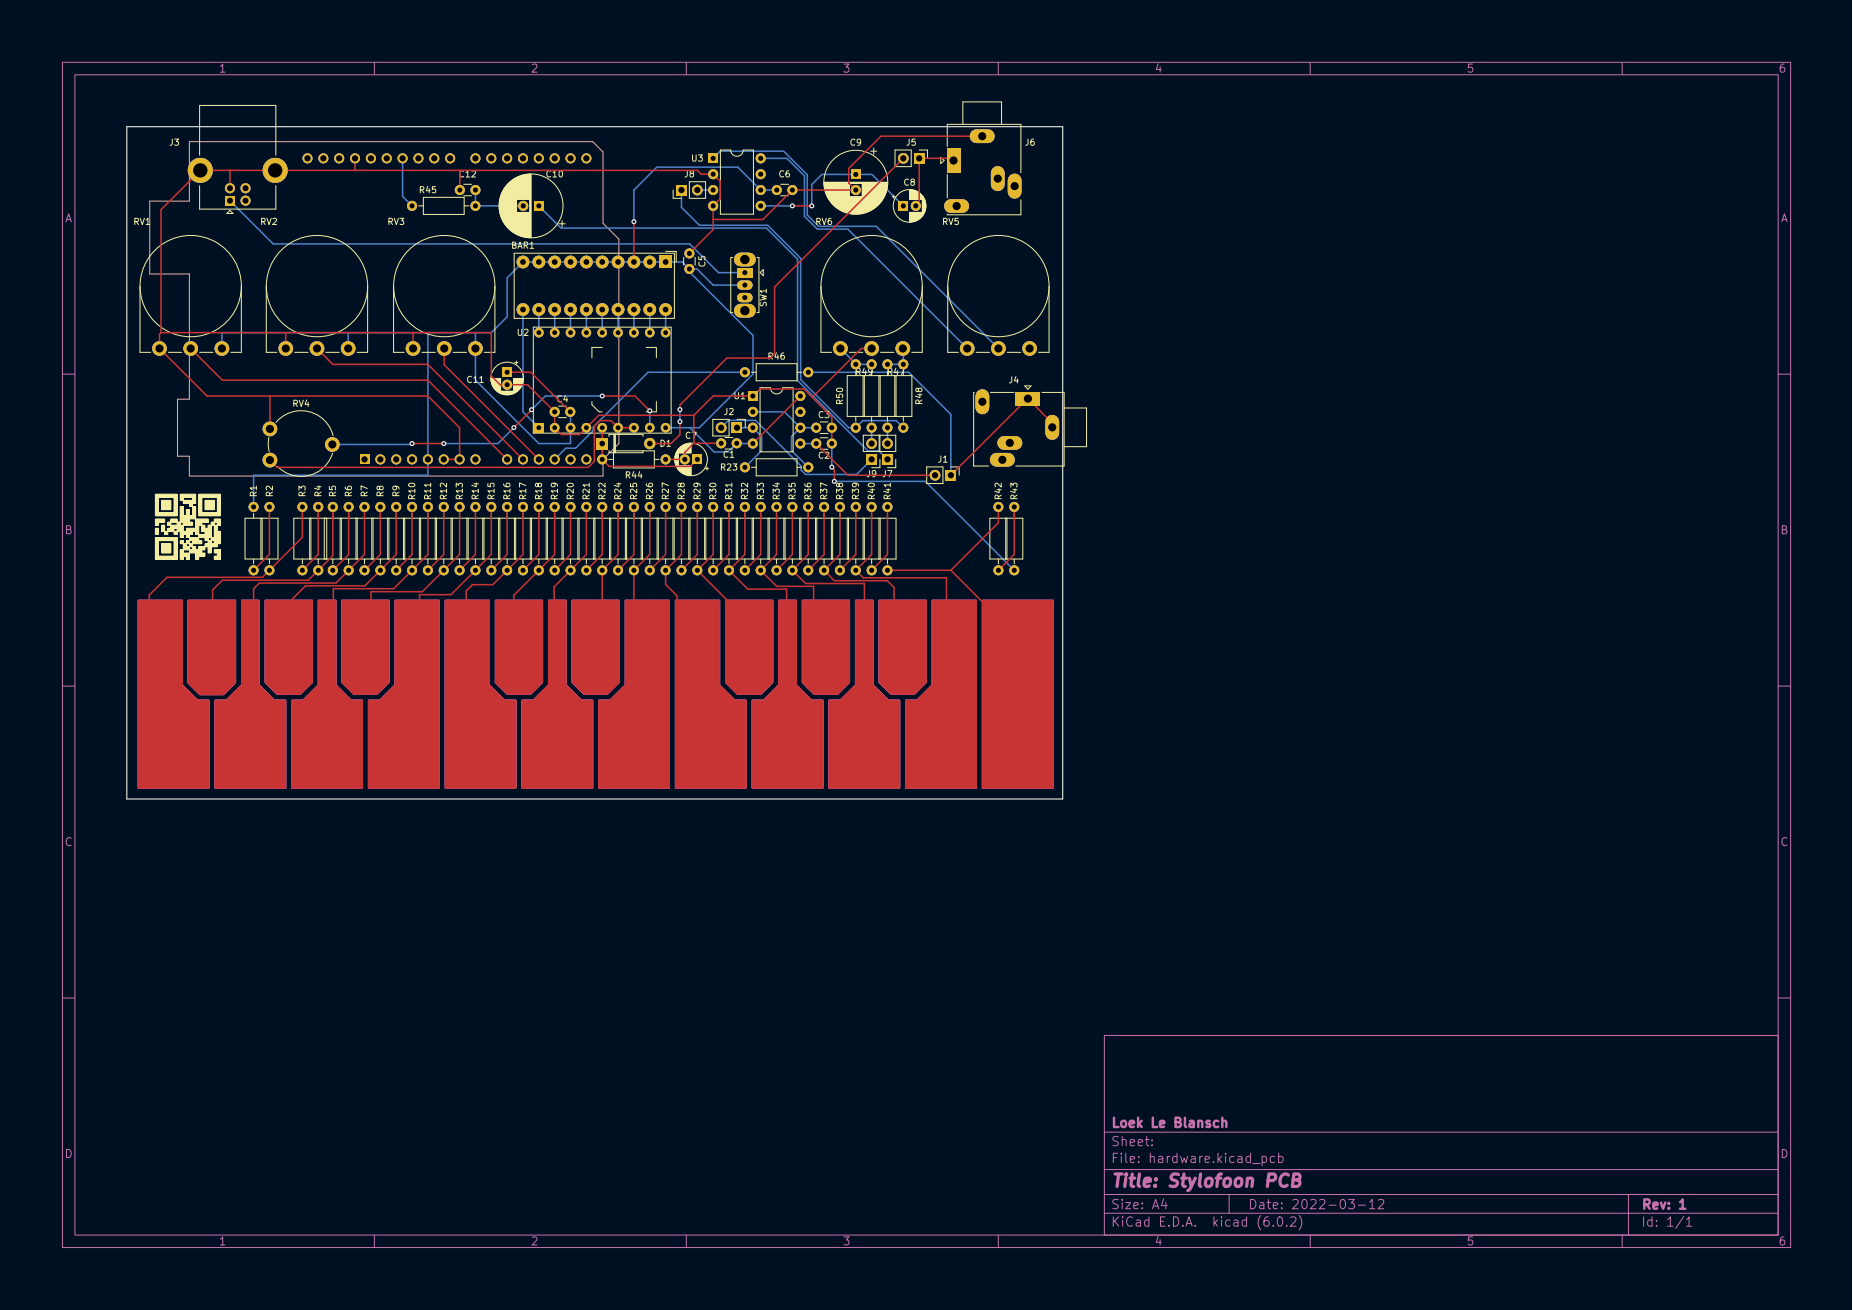
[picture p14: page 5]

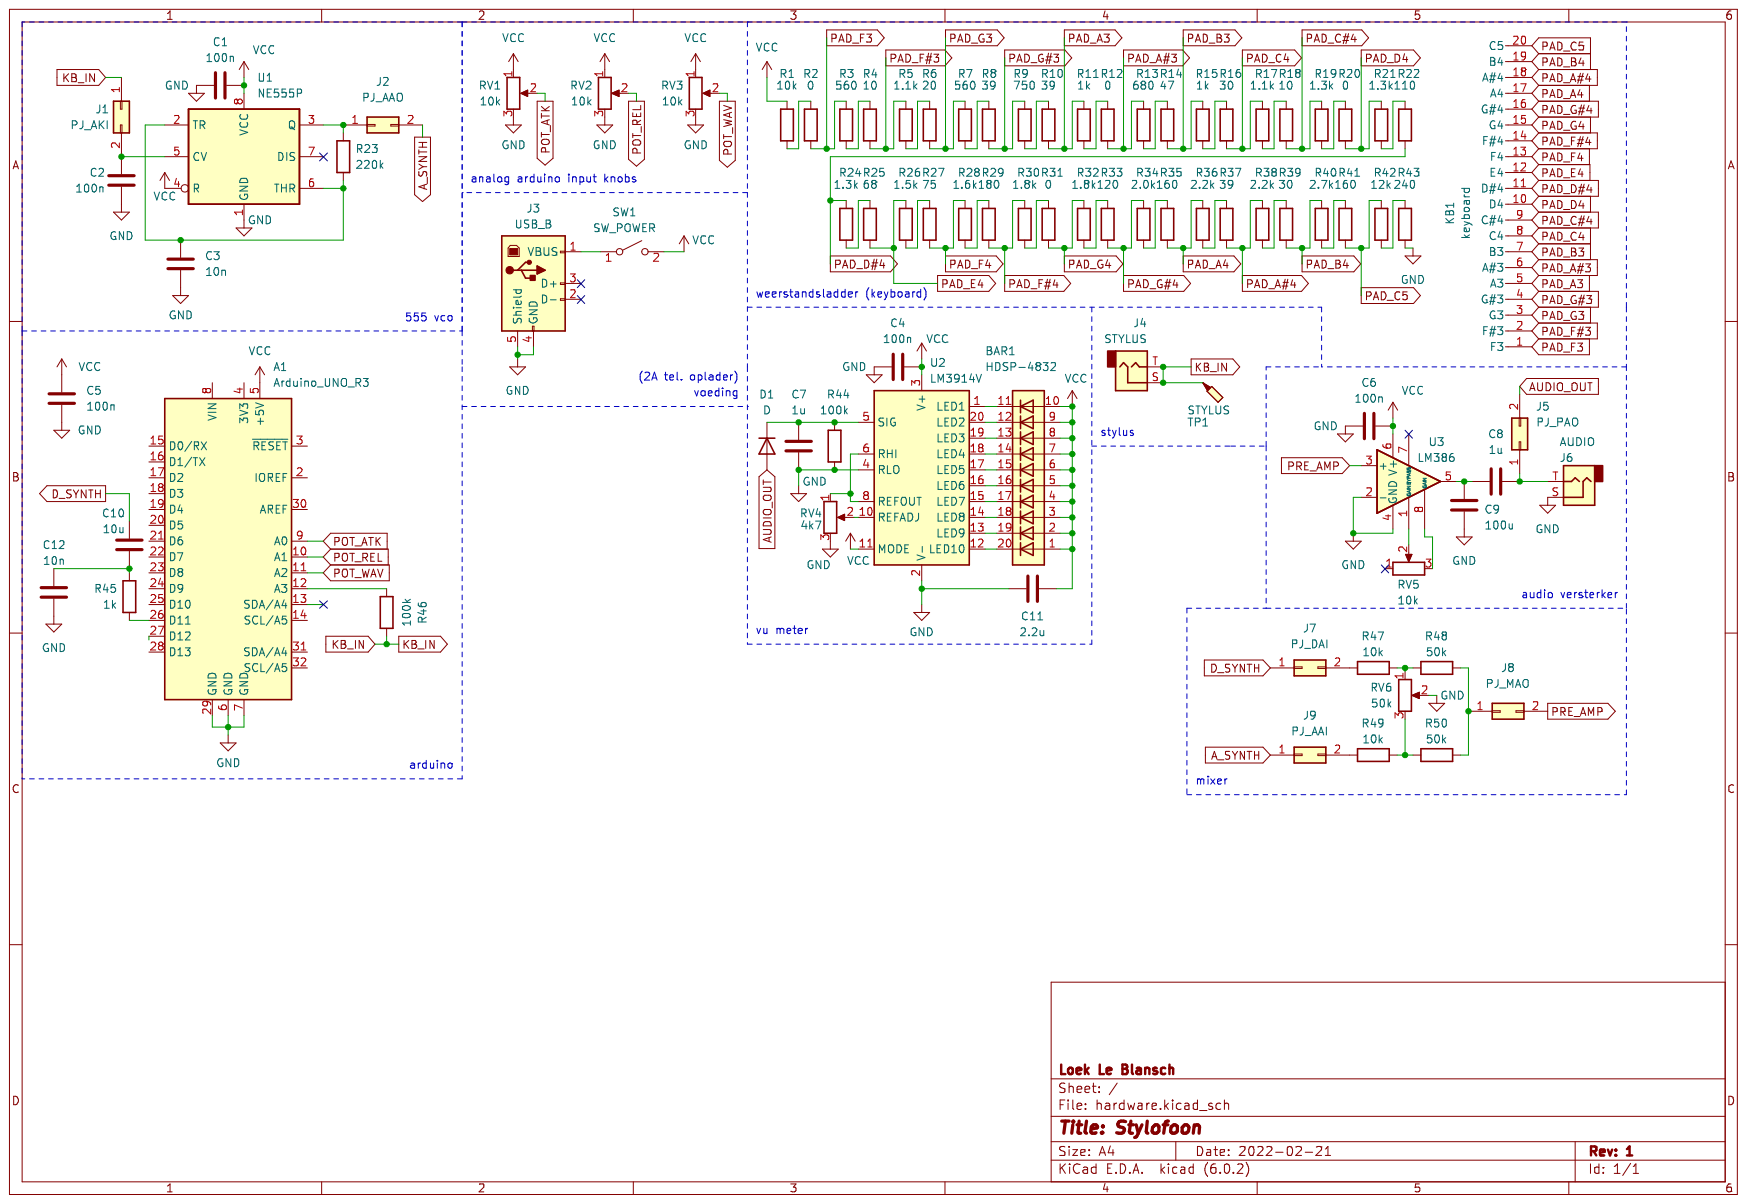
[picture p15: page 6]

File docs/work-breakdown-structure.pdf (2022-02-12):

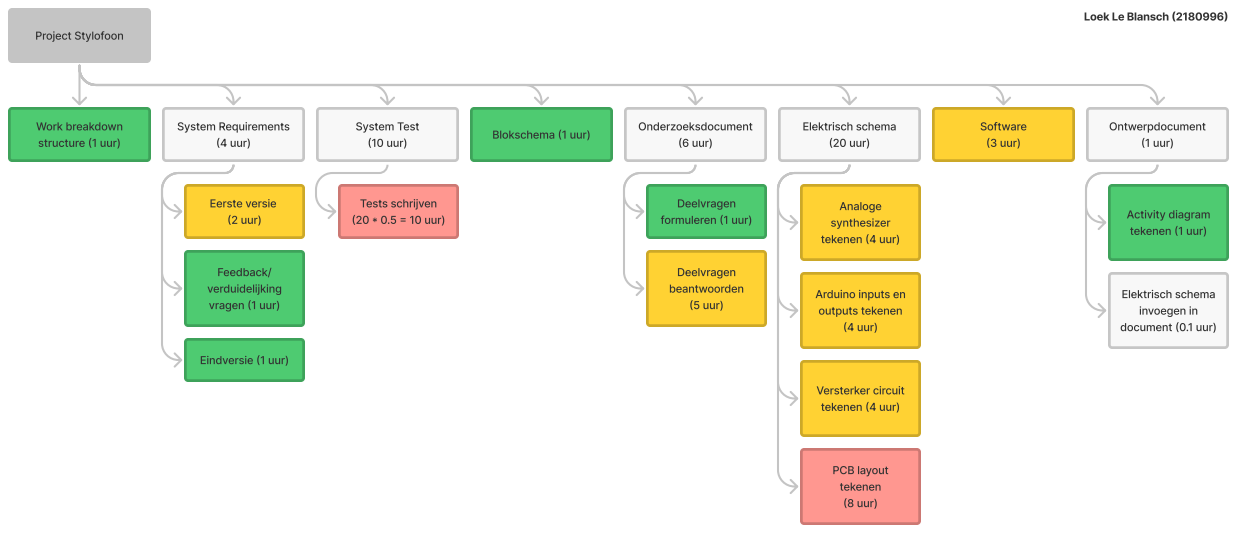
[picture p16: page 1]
Project Stylofoon; Work breakdown; structure (1 uur); Eerste versie; (2 uur); Deelvragen beantwoorden; (5 uur); Deelvragen; formuleren (1 uur); Analoge synthesizer; tekenen (4 uur); Activity diagram tekenen (1 uur); Elektrisch schema; invoegen in; document (0.1 uur); Versterker circuit; PCB layout tekenen; (8 uur); Tests schrijven; (20 * 0.5 = 10 uur); Eindversie (1 uur); Feedback/; verduidelijking; vragen (1 uur); System Requirements; (4 uur); System Test; (10 uur); Blokschema (1 uur)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

Loek Le Blansch (2180996)

Arduino inputs en
outputs tekenen
(4 uur)

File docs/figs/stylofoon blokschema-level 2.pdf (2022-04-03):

Arduino Uno (synthesizer digitaal); 555 timer circuit (synthesizer analoog); Versterker en mixer; VU-meter; Draaiknoppen; Keyboard invoer; Geluidsuitvoer; VU-display; Stand knoppen




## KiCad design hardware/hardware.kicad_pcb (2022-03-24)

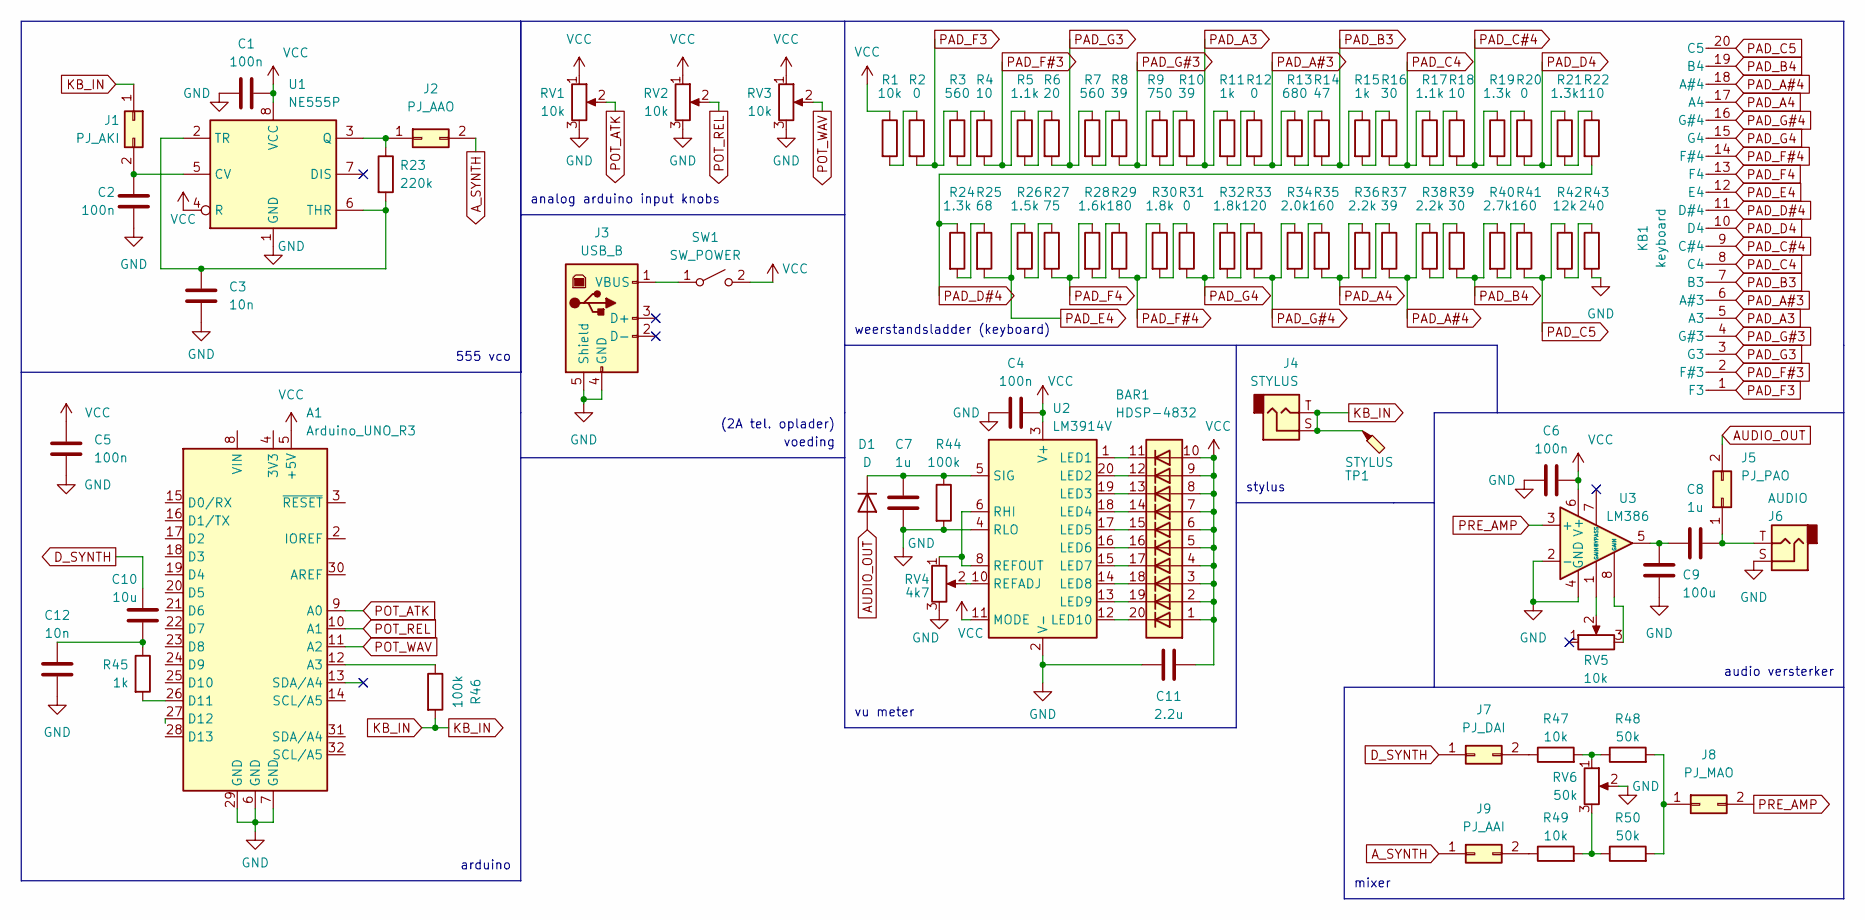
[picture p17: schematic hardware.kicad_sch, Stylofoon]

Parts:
A1: Arduino_UNO_R3
BAR1: HDSP-4832
C1, C2, C4, C5, C6: 100n; C_Disc_D3.0mm_W1.6mm_P2.50mm
C3, C12: 10n; C_Disc_D3.0mm_W1.6mm_P2.50mm
C7, C8: 1u; CP_Radial_D5.0mm_P2.00mm
C9: 100u; CP_Radial_D10.0mm_P2.50mm
C10: 10u; CP_Radial_D10.0mm_P2.50mm
C11: 2.2u; CP_Radial_D5.0mm_P2.00mm
D1: D; D_A-405_P7.62mm_Horizontal
J1: PJ_AKI; PinHeader_1x02_P2.54mm_Vertical
J2: PJ_AAO; PinHeader_1x02_P2.54mm_Vertical
J3: USB_B; USB_B_Lumberg_2411_02_Horizontal
J4: STYLUS; Jack_3.5mm_Ledino_KB3SPRS_Horizontal
J5: PJ_PAO; PinHeader_1x02_P2.54mm_Vertical
J6: AUDIO; Jack_3.5mm_Ledino_KB3SPRS_Horizontal
J7: PJ_DAI; PinHeader_1x02_P2.54mm_Vertical
J8: PJ_MAO; PinHeader_1x02_P2.54mm_Vertical
J9: PJ_AAI; PinHeader_1x02_P2.54mm_Vertical
KB1: keyboard
R1, R47, R49: 10k; R_Axial_DIN0207_L6.3mm_D2.5mm_P10.16mm_Horizontal
R2, R12, R20, R31: 0; R_Axial_DIN0207_L6.3mm_D2.5mm_P10.16mm_Horizontal
R3, R7: 560; R_Axial_DIN0207_L6.3mm_D2.5mm_P10.16mm_Horizontal
R4, R18: 10; R_Axial_DIN0207_L6.3mm_D2.5mm_P10.16mm_Horizontal
R5, R17: 1.1k; R_Axial_DIN0207_L6.3mm_D2.5mm_P10.16mm_Horizontal
R6: 20; R_Axial_DIN0207_L6.3mm_D2.5mm_P10.16mm_Horizontal
R8, R10, R37: 39; R_Axial_DIN0207_L6.3mm_D2.5mm_P10.16mm_Horizontal
R9: 750; R_Axial_DIN0207_L6.3mm_D2.5mm_P10.16mm_Horizontal
R11, R15, R45: 1k; R_Axial_DIN0207_L6.3mm_D2.5mm_P10.16mm_Horizontal
R13: 680; R_Axial_DIN0207_L6.3mm_D2.5mm_P10.16mm_Horizontal
R14: 47; R_Axial_DIN0207_L6.3mm_D2.5mm_P10.16mm_Horizontal
R16, R39: 30; R_Axial_DIN0207_L6.3mm_D2.5mm_P10.16mm_Horizontal
R19, R21, R24: 1.3k; R_Axial_DIN0207_L6.3mm_D2.5mm_P10.16mm_Horizontal
R22: 110; R_Axial_DIN0207_L6.3mm_D2.5mm_P10.16mm_Horizontal
R23: 220k; R_Axial_DIN0207_L6.3mm_D2.5mm_P10.16mm_Horizontal
R25: 68; R_Axial_DIN0207_L6.3mm_D2.5mm_P10.16mm_Horizontal
R26: 1.5k; R_Axial_DIN0207_L6.3mm_D2.5mm_P10.16mm_Horizontal
R27: 75; R_Axial_DIN0207_L6.3mm_D2.5mm_P10.16mm_Horizontal
R28: 1.6k; R_Axial_DIN0207_L6.3mm_D2.5mm_P10.16mm_Horizontal
R29: 180; R_Axial_DIN0207_L6.3mm_D2.5mm_P10.16mm_Horizontal
R30, R32: 1.8k; R_Axial_DIN0207_L6.3mm_D2.5mm_P10.16mm_Horizontal
R33: 120; R_Axial_DIN0207_L6.3mm_D2.5mm_P10.16mm_Horizontal
R34: 2.0k; R_Axial_DIN0207_L6.3mm_D2.5mm_P10.16mm_Horizontal
R35, R41: 160; R_Axial_DIN0207_L6.3mm_D2.5mm_P10.16mm_Horizontal
R36, R38: 2.2k; R_Axial_DIN0207_L6.3mm_D2.5mm_P10.16mm_Horizontal
R40: 2.7k; R_Axial_DIN0207_L6.3mm_D2.5mm_P10.16mm_Horizontal
R42: 12k; R_Axial_DIN0207_L6.3mm_D2.5mm_P10.16mm_Horizontal
R43: 240; R_Axial_DIN0207_L6.3mm_D2.5mm_P10.16mm_Horizontal
R44, R46: 100k; R_Axial_DIN0207_L6.3mm_D2.5mm_P10.16mm_Horizontal
R48, R50: 50k; R_Axial_DIN0207_L6.3mm_D2.5mm_P10.16mm_Horizontal
RV1, RV2, RV3, RV5: 10k; potm
RV4: 4k7; Potentiometer_Piher_PT-10-V10_Vertical
RV6: 50k; potm
SW1: SW_POWER; SW_Slide_1P2T_CK_OS102011MS2Q
TP1: STYLUS
U1: NE555P; DIP-8_W7.62mm
U2: LM3914V; avans-lm3914v
U3: LM386; DIP-8_W7.62mm

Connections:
AUDIO_OUT: D1.2 (A), J5.2
A_SYNTH: J2.2, J9.1
D_SYNTH: C10.1, J7.1
GND: A1.6 (GND), A1.7 (GND), A1.29 (GND), C1.1, C2.2, C3.2, C4.1, C5.1, C6.1, C7.2, C9.2, C11.2, C12.2, J3.4 (GND), J3.5 (Shield), J6.S, R43.2, R44.2, RV1.3, RV2.3, RV3.3, RV4.3, RV6.2, U1.1 (GND), U2.2 (V-), U2.4 (RLO), U3.2 (-), U3.4 (GND)
KB_IN: J1.1, J4.S, J4.T, R46.2, TP1.1
unnamed: A1.12 (A3), R46.1
unnamed: A1.26 (D11), R45.2
unnamed: BAR1.11 (K), U2.1 (LED1)
unnamed: BAR1.12 (K), U2.20 (LED2)
unnamed: BAR1.13 (K), U2.19 (LED3)
unnamed: BAR1.14 (K), U2.18 (LED4)
unnamed: BAR1.15 (K), U2.17 (LED5)
unnamed: BAR1.16 (K), U2.16 (LED6)
unnamed: BAR1.17 (K), U2.15 (LED7)
unnamed: BAR1.18 (K), U2.14 (LED8)
unnamed: BAR1.19 (K), U2.13 (LED9)
unnamed: BAR1.20 (K), U2.12 (LED10)
unnamed: C2.1, J1.2, U1.5 (CV)
unnamed: C3.1, R23.2, U1.2 (TR), U1.6 (THR)
unnamed: C7.1, D1.1 (K), R44.1, U2.5 (SIG)
unnamed: C8.1, C9.1, U3.5
unnamed: C8.2, J5.1, J6.T
unnamed: C10.2, C12.1, R45.1
unnamed: J2.1, R23.1, U1.3 (Q)
unnamed: J3.1 (VBUS), SW1.1 (A)
unnamed: J7.2, R47.1
unnamed: J8.1, R48.2, R50.2
unnamed: J9.2, R49.1
unnamed: R1.2, R2.1
unnamed: R3.2, R4.1
unnamed: R5.2, R6.1
unnamed: R7.2, R8.1
unnamed: R9.2, R10.1
unnamed: R11.2, R12.1
unnamed: R13.2, R14.1
unnamed: R15.2, R16.1
unnamed: R17.2, R18.1
unnamed: R19.2, R20.1
unnamed: R21.2, R22.1
unnamed: R24.2, R25.1
unnamed: R26.2, R27.1
unnamed: R28.2, R29.1
unnamed: R30.2, R31.1
unnamed: R32.2, R33.1
unnamed: R34.2, R35.1
unnamed: R36.2, R37.1
unnamed: R38.2, R39.1
unnamed: R40.2, R41.1
unnamed: R42.2, R43.1
unnamed: R47.2, R48.1, RV6.1
unnamed: R49.2, R50.1, RV6.3
unnamed: RV4.1, U2.6 (RHI), U2.8 (REFOUT)
unnamed: RV4.2, U2.10 (REFADJ)
unnamed: RV5.2, U3.1 (GAIN)
unnamed: RV5.3, U3.8 (GAIN)
PAD_A3: KB1.5 (A3), R10.2, R11.1
PAD_A4: KB1.17 (A4), R35.2, R36.1
PAD_A#3: KB1.6 (A#3), R12.2, R13.1
PAD_A#4: KB1.18 (A#4), R37.2, R38.1
PAD_B3: KB1.7 (B3), R14.2, R15.1
PAD_B4: KB1.19 (B4), R39.2, R40.1
PAD_C4: KB1.8 (C4), R16.2, R17.1
PAD_C5: KB1.20 (C5), R41.2, R42.1
PAD_C#4: KB1.9 (C#4), R18.2, R19.1
PAD_D4: KB1.10 (D4), R20.2, R21.1
PAD_D#4: KB1.11 (D#4), R22.2, R24.1
PAD_E4: KB1.12 (E4), R25.2, R26.1
PAD_F3: KB1.1 (F3), R2.2, R3.1
PAD_F4: KB1.13 (F4), R27.2, R28.1
PAD_F#3: KB1.2 (F#3), R4.2, R5.1
PAD_F#4: KB1.14 (F#4), R29.2, R30.1
PAD_G3: KB1.3 (G3), R6.2, R7.1
PAD_G4: KB1.15 (G4), R31.2, R32.1
PAD_G#3: KB1.4 (G#3), R8.2, R9.1
PAD_G#4: KB1.16 (G#4), R33.2, R34.1
POT_ATK: A1.9 (A0), RV1.2
POT_REL: A1.10 (A1), RV2.2
POT_WAV: A1.11 (A2), RV3.2
PRE_AMP: J8.2, U3.3 (+)
VCC: A1.5 (+5V), BAR1.1 (A), BAR1.2 (A), BAR1.3 (A), BAR1.4 (A), BAR1.5 (A), BAR1.6 (A), BAR1.7 (A), BAR1.8 (A), BAR1.9 (A), BAR1.10 (A), C1.2, C4.2, C5.2, C6.2, C11.1, R1.1, RV1.1, RV2.1, RV3.1, SW1.2 (B), U1.4 (R), U1.8 (VCC), U2.3 (V+), U2.11 (MODE), U3.6 (V+)

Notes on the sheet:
arduino
555 vco
analog arduino input knobs
vu meter
audio versterker
voeding
mixer
(2A tel. oplader)
stylus
weerstandsladder (keyboard)

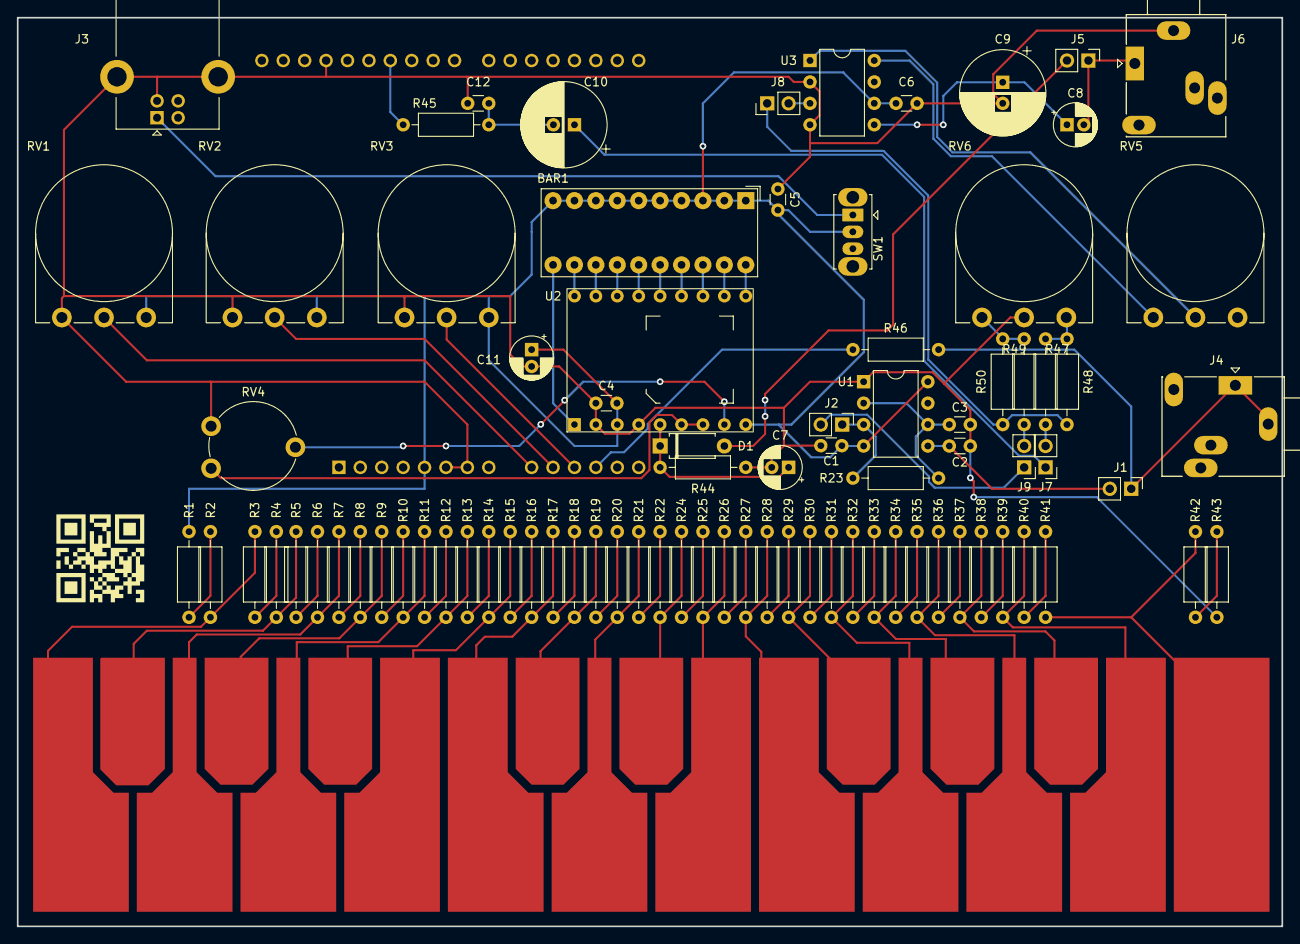
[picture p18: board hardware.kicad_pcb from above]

Board: 2 copper layers, 150.0 x 107.8 mm, 85 parts (1 on the bottom side), 80 nets.

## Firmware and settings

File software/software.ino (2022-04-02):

#include "lib/the_synth/synth.h"

#define KB_SAMPLES 100
#define PINOUT_AUDIO_OUT CHA
#define PINOUT_POT_ATK A0
#define PINOUT_POT_REL A1
#define PINOUT_POT_WAV A2
#define PINOUT_KB_IN A3

synth bernard;

void setup() {
	// i/o instellen
	pinMode(PINOUT_AUDIO_OUT, OUTPUT);
	pinMode(PINOUT_POT_ATK, INPUT);
	pinMode(PINOUT_POT_WAV, INPUT);
	pinMode(PINOUT_POT_REL, INPUT);
	pinMode(PINOUT_KB_IN, INPUT);

	// the_synth initialiseren
	bernard.begin(PINOUT_AUDIO_OUT);

	// gekopiëerd van een stukje voorbeeldcode, alleen de golfvorm maakt hier uit
	bernard.setupVoice(0,SINE,60,ENVELOPE0,90,64);
	bernard.setupVoice(1,TRIANGLE,62,ENVELOPE1,90,64);
	bernard.setupVoice(2,SAW,64,ENVELOPE2,90,64);
	bernard.setupVoice(3,SQUARE,67,ENVELOPE0,90,64);
}

void loop() {
	// lees potmeters uit
	unsigned int pot_rel = analogRead(PINOUT_POT_REL);
	unsigned int pot_atk = analogRead(PINOUT_POT_ATK);
	unsigned int pot_wav = analogRead(PINOUT_POT_WAV);

	// neem een gemiddelde meting van de keyboard ingangsspanning
	double average = 0.0;
	for (int i = 0; i < KB_SAMPLES; i++)
		average += ((double) analogRead(PINOUT_KB_IN)) / KB_SAMPLES;

	// geplukte getallen om de klank aan te passen
	unsigned char env = pot_rel / (1024/4);
	unsigned char mod = 572 + pot_atk / 100;
	unsigned char wave = pot_wav / (1024/4);

	// synth kiezen / klank bijwerken
	bernard.setEnvelope(wave, env);
	// synth triggeren
	bernard.mTrigger(wave, 116 - average / 10);
	delay(500 - pot_atk / 5);
}

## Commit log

2022-02-15 added (incomplete) tests
    [test_setup.kicad_pcb, test_setup.kicad_sch]
2022-02-17 more research
    [hardware.kicad_sch]
2022-02-19 more test schematics
    [hardware.kicad_sch]
2022-02-21 partitioning schematics
    [hardware.kicad_sch]
2022-02-21 mode hardware tests
    [555_vco.kicad_sch, hardware.kicad_pcb, hardware.kicad_sch]
2022-02-21 test arduino sketch
2022-02-22 added lab tests
    [hardware.kicad_sch]
2022-02-22 electric schematics and typo fix
    [hardware.kicad_sch, meetresultaten.ods]
2022-02-27 more work
    [555_vco.kicad_sch, hardware.kicad_pcb, hardware.kicad_sch]
2022-03-08 more schematics
    [hardware.kicad_pcb, hardware.kicad_sch]
2022-03-09 more hardware
    [hardware.kicad_pcb, hardware.kicad_sch]
2022-03-10 more hardware
    amplifier circuit done
    [hardware.kicad_pcb, hardware.kicad_sch]
2022-03-10 more hardware (almost done!)
    [hardware.kicad_pcb, hardware.kicad_sch]
2022-03-12 hardware done
    [hardware-B_Cu.gbr, hardware-B_Mask.gbr, hardware-B_Paste.gbr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]
2022-03-12 final hardware version
    [hardware-B_Cu.gbr, hardware-B_Mask.gbr, hardware-B_Paste.gbr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]
2022-03-24 hardware gesoldeerd
    [hardware.kicad_pcb, hardware.kicad_sch]
2022-04-07 added image of finished and assembled pcb
